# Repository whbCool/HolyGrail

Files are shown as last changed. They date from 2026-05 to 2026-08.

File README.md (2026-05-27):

# TEA@CPP Escape Room 2026: The Holy Grail

update_noTB

The _Holy Grail_ is a custom PCB, designed for the Indiana Jones puzzle as a part of TEA@CPP's "Retro Rewind" 2026 Escape Room. 

This repository includes the KiCad schematic, as well as the code database for the board.

For more details on the code, check out [the introductory walkthrough here](walkthrough.md).

Major Components:
- ESP32-WROOM-32UE
- SC16IS752IPW_128
- CD74HC138QM96Q1
- SN74LVC1G125DBVT
- CDCLVC1106PWR
- 7447715003
- LMR33640
- AP63205WU-7
- 5747842-2
- W5500
- USBLC6-2SC6
- TMJ0026ABNL
- MMBT3904
- CP2102N-A02-GQFN24
- 1812L150_24MR
- LM393DR

Design Requirements:
1. Read data from 12 LD2410C sensors using SPI-to-UART converters.
2. Aggregate sensor data and package it into a JSON payload to be sent to an MQTT broker.
3. USB port for programming and debugging.

More Info: https://drive.google.com/drive/folders/14Y64IZpTN127Q0mva5SdtTZ1QgllTaBJ

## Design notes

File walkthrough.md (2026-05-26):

# Walkthrough: Holy Grail Board Programming Completed

We have successfully designed, implemented, and organized a robust, modular, and thread-safe firmware architecture for the **Holy Grail** custom radar aggregator PCB! The codebase is ready to be compiled, flashed, and tested.

---

## What We Accomplished

### 1. Multiplexed SPI-to-UART Bridge Driver (`sc16is752` Component)
* **Custom Driver ([sc16is752.h](file:///c:/Users/remas/Desktop/PCBs/DarkMagic/Code/HolyGrail/main/sc16is752.h) & [sc16is752.c](file:///c:/Users/remas/Desktop/PCBs/DarkMagic/Code/HolyGrail/main/sc16is752.c)):** Built a complete driver that performs SPI transactions with the six **SC16IS752** chips.
* **Line Decoder Routing:** Built hardware chip-selection functions that dynamically set the binary address on the **CD74HC138** line decoder (`GPIO25`, `26`, `32`) and pull the Active-High Enable pin (`GPIO33`) `HIGH` to assert the target chip's Chip Select (`*CS`).
* **Resolved MISO Bus Contention:** Programmed dynamic control of the **`IC12` MISO buffer OE pin** via **`GPIO27`**. The driver pulls `GPIO27` `LOW` only during an SPI transaction with the SC16IS752 chips and drives it `HIGH` (tri-stating `IC12`) immediately after. This allows the **W5500** to utilize the shared `MISO` line without any electrical conflicts!
* **Exact Integer Baud Division:** Calculated and programmed divisors for the standard high-speed baud rates (e.g. **230400 bps** or **460800 bps**) using the **14.7456 MHz** crystal, guaranteeing a **0.00% baud rate error**.

### 2. W5500 Ethernet Stack & Static IP (`ethernet` Module)
* **Driver Setup ([ethernet.h](file:///c:/Users/remas/Desktop/PCBs/DarkMagic/Code/HolyGrail/main/ethernet.h) & [ethernet.c](file:///c:/Users/remas/Desktop/PCBs/DarkMagic/Code/HolyGrail/main/ethernet.c)):** Configured the ESP-IDF standard Ethernet driver with W5500 SPI MAC and PHY options, mapping hardware Chip Select (`GPIO5`) and Reset (`GPIO15`).
* **ESP-NETIF Event Handling:** Attached the Ethernet driver to the ESP-NETIF TCP/IP stack with custom static IP parameters (`192.168.1.150`, gateway `192.168.1.1`) and custom DNS (`192.168.1.1`).

### 3. MQTT JSON Telemetry Publisher (`mqtt` Module)
* **Client Setup ([mqtt.h](file:///c:/Users/remas/Desktop/PCBs/DarkMagic/Code/HolyGrail/main/mqtt.h) & [mqtt.c](file:///c:/Users/remas/Desktop/PCBs/DarkMagic/Code/HolyGrail/main/mqtt.c)):** Configured the asynchronous ESP-MQTT client to connect to `mqtt://192.168.1.100:1883` once Ethernet acquires an IP.
* **JSON Serialization:** Handles robust string packaging of telemetry data for all 12 radar sensors and publishes it to `holygrail/radar/telemetry` at 10Hz.

### 4. logical-to-Physical Port Mapping & Aggregation (`main`)
* **Logical Mapping ([main.c](file:///c:/Users/remas/Desktop/PCBs/DarkMagic/Code/HolyGrail/main/main.c)):** Built a static mapping table linking logical sensor indexes `Sensor Bank A (1..6)` and `Sensor Bank B (1..6)` to their physical routing connections (U1-U7 chip index and UART channel A/B) on the PCB.
* **FreeRTOS Dual-Core Tasks:**
  1. **`radar_aggregator_task` (Core 0):** High-priority task that sequentially polls all 12 physical UART channels, parses raw frame packets using the `ld2410c` parser, and updates a global state structure.
  2. **`telemetry_publish_task` (Core 1):** Medium-priority task that packages the latest state values into a JSON MQTT payload, publishes it, and toggles the heartbeat `STATUS` LED (`GPIO21`).
  3. **Thread Safety:** Handled race conditions by wrapping table accesses in a FreeRTOS Mutex.

---

## Codebase Architecture

```mermaid
classDiagram
    class MainApp {
        +app_main()
        +init_board_hardware()
        +radar_aggregator_task()
        +telemetry_publish_task()
    }
    class SC16IS752_Driver {
        +sc16is752_init(config)
        +sc16is752_select_chip(idx)
        +sc16is752_deselect_all()
        +sc16is752_read_reg(chip, chan, reg, val)
        +sc16is752_write_reg(chip, chan, reg, val)
        +sc16is752_configure_uart(chip, chan, baud)
        +sc16is752_read_bytes(chip, chan, buf, max)
    }
    class Ethernet_Driver {
        +ethernet_init(config)
        +ethernet_is_connected()
    }
    class MQTT_Publisher {
        +mqtt_init()
        +mqtt_is_connected()
        +mqtt_publish_telemetry(payload)
    }
    class LD2410C_Parser {
        +ld2410c_parse_target_data(frame, len, data)
    }

    MainApp --> SC16IS752_Driver : Polls U1-U7
    MainApp --> Ethernet_Driver : Starts W5500
    MainApp --> MQTT_Publisher : Sends JSON
    MainApp --> LD2410C_Parser : Parses Bytes
```

---

## How to Compile & Verify

Since you have an established ESP-IDF environment in VS Code pointing to `C:\esp\v6.0.1\esp-idf`, compiling is extremely simple:

### Step 1: Compile in VS Code
1. Open the project folder in VS Code.
2. Click the **Build** icon (gear icon) in the bottom status bar, or press `Ctrl+E` followed by `B`.
3. The VS Code ESP-IDF extension will handle the virtual environment and automatically compile the project into the `build/` directory.

### Step 2: Flash the Board
1. Connect the Holy Grail board to your computer using a USB-C cable (CP2102N UART bridge).
2. Ensure the correct COM port is selected in the bottom status bar.
3. Click the **Flash** icon (lightning bolt icon) in the status bar to upload the compiled binary to the ESP32.

### Step 3: Verify Telemetry
1. Open the **ESP-IDF Monitor** in VS Code (monitor icon) to view the real-time logging output.
2. You will see:
   * **W5500 initialization status** and network link updates.
   * **Static IP printouts** once the link gets initialized.
   * **Real-time sensor parsing states** (Moving, Stationary, or None) as target values change.
3. Connect a laptop to the local Ethernet network, run an MQTT Broker (like Mosquitto) on `192.168.1.100`, and use **MQTT Explorer** subscribed to `holygrail/radar/telemetry` to view the aggregated JSON frames arriving at 10Hz!

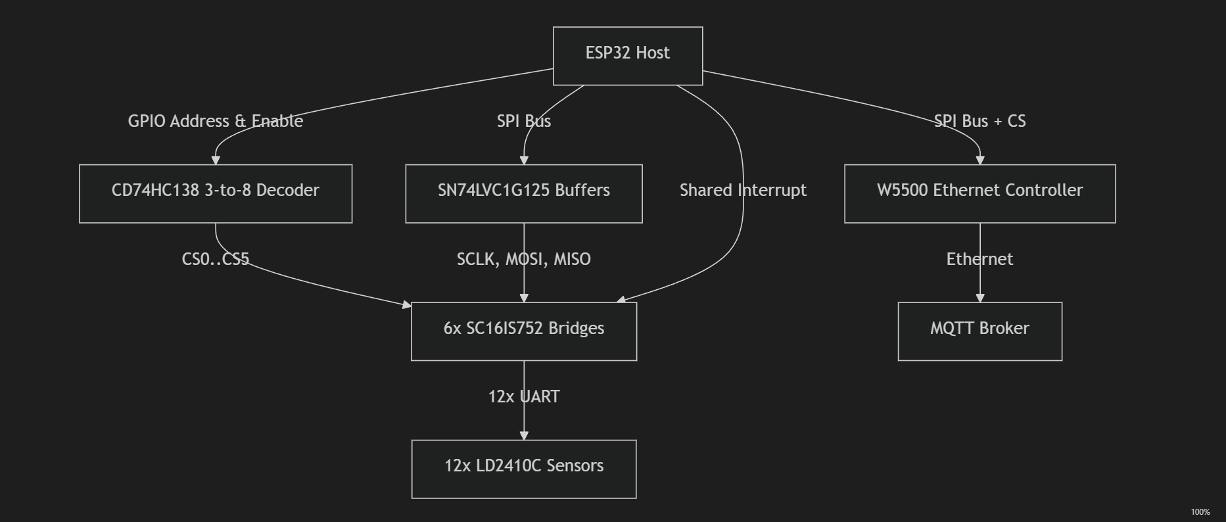
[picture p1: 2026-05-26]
Logic Diagram.png

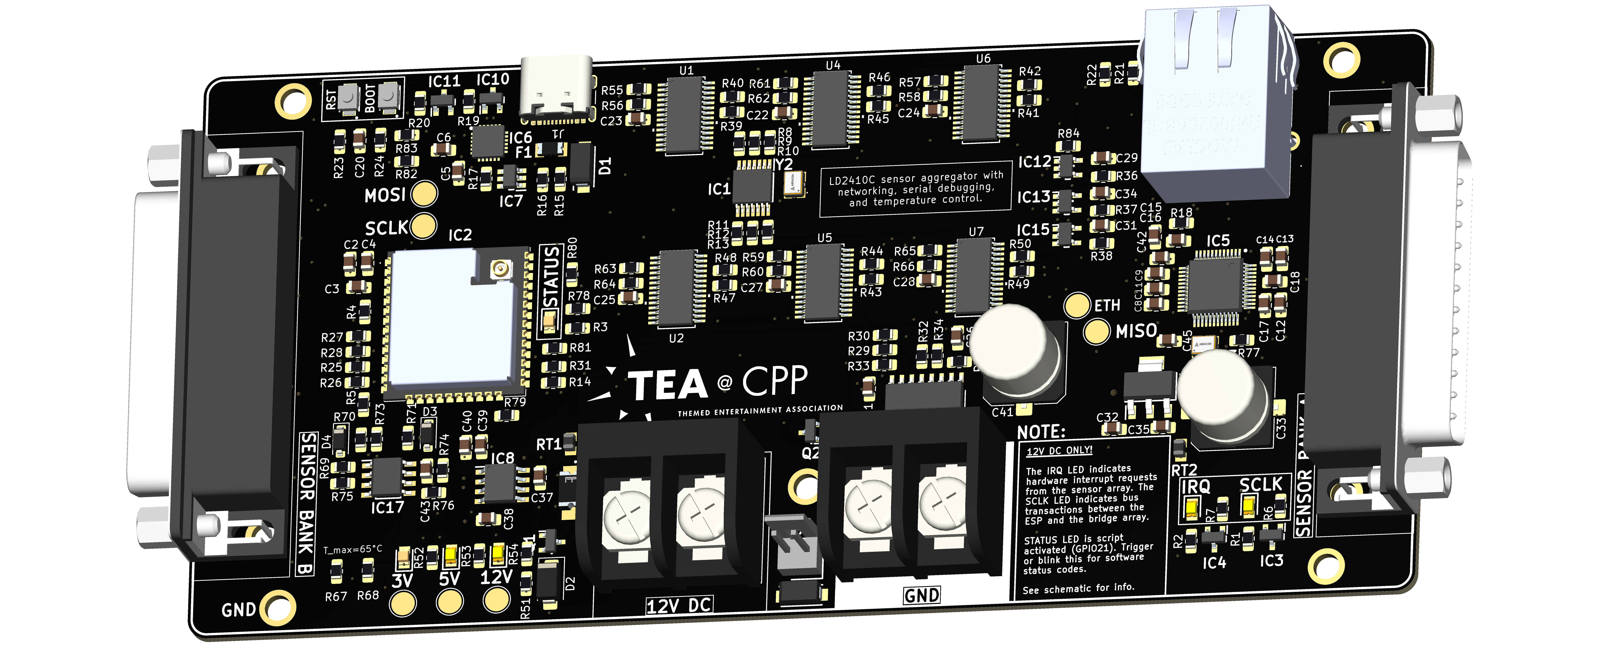
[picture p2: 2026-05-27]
PCB/DarkMagic.png

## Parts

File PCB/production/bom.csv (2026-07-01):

Designator | Footprint | Quantity | Value | LCSC Part #
12V1 | LEDC2012X90N | 1 | HSMC-C170
3V1, STATUS1 | LEDC2012X80N | 2 | HSMG-C170
5V1 | LEDC2012X90N | 1 | HSMA-C170
C1, C10, C12, C13, C14, C15, C16, C17, C18, C19, C2, C20, C21, C22, C23, C24, C25, C26, C27, C28, C29, C30, C31, C34, C35, C37, C42, C43, C44, C45, C46, C47, C50, C6, C8, C9 | 0805 | 36 | 0.1uF
C11 | 0805 | 1 | 10nF
C3, C32, C38, C4 | 0805 | 4 | 10uF
C33 | C_Elec_10x10.2 | 1 | 33uF
C39, C40, C49, C52, C53 | 0805 | 5 | 22uF
C41 | C_Elec_10x10.2 | 1 | 47uF
C48 | 0805 | 1 | 1uF
C5, C7 | 0805 | 2 | 4.7uF
C51 | 0805 | 1 | 220nF
C54 | 0805 | 1 | 39pF
D1, D5 | DIOM5226X230N | 2 | B130-13-F
D2 | D_SMA | 1 | SMBJ26A
D3, D4 | D_SOD-123 | 2 | 1N4148W
F1 | FUSC3216X74N | 1 | NANOSMDC050F_13.2-2
F2 | 1812L010DR | 1 | 1812L150_24MR
IC1 | SOP65P640X120-14N | 1 | 5PB1106PGGI8
IC10, IC11, IC3, IC4 | SOT95P240X120-3N | 4 | MMBT3904-AQ
IC12, IC13, IC15 | SOT95P280X145-5N | 3 | SN74LVC1G125DBVT
IC14 | SOT230P700X180-4N | 1 | LM3940IMP-3.3_NOPB
IC17 | SOIC127P600X175-8N | 1 | LM393DR
IC2 | ESP32WROOM32UEN16 | 1 | ESP32-WROOM-32UE-N16
IC5 | QFP50P900X900X160-48N | 1 | W5500
IC6 | QFN50P400X400X80-25N-D | 1 | CP2102N-A02-GQFN24
IC7 | SOT95P280X145-6N | 1 | USBLC6-2SC6
IC8 | SOIC127P600X170-9N | 1 | LMR33640ADDAR
IRQ1, SCLK1 | LEDC2012X90N | 2 | HSMN-C170
J1 | USB_C_Receptacle_GCT_USB4105-xx-A_16P_TopMnt_Horizontal | 1 | USB_C_Receptacle_USB2.0_16P
J2 | TMJ0026ABNL | 1 | TMJ0026ABNL
J3, J6 | 57478422 | 2 | 5747842-2
J7 | SHDR2W69P0X250_1X2_500X530X1040P | 1 | 171825-2
L1 | L_12x12mm_H4.5mm | 1 | 7447715003
Q1 | SOT95P237X112-3N | 1 | SQ2319ADS-T1_BE3
Q2 | SOT95P237X112-3N | 1 | SQ2348ES-T1_BE3
R1, R2, R21, R22, R3 | 0805 | 5 | 330
R10, R11, R12, R13, R29, R30, R32, R33, R34, R35, R36, R37, R38, R39, R40, R41, R42, R43, R44, R45, R46, R47, R48, R49, R50, R55, R56, R57, R58, R59, R60, R61, R62, R63, R64, R65, R66, R77, R78, R79, R8, R80, R81, R9 | 0805 | 44 | 33
R14, R17, R19, R20, R23, R24, R25, R26, R27, R28, R4, R5, R51, R69, R70, R71, R72, R73, R74, R84, R88, R93 | 0805 | 22 | 10k
R15, R16 | 0805 | 2 | 5.1k
R18 | 0805 | 1 | 12.4k
R31, R54, R6, R7 | 0805 | 4 | 4.7k
R52 | 0805 | 1 | 680
R53 | 0805 | 1 | 1.5k
R67, R68 | 0805 | 2 | 2.55K
R75, R76 | 0805 | 2 | 1M
R82 | 0805 | 1 | 22.1k
R83 | 0805 | 1 | 47.5k
R85 | 0805 | 1 | 24.9k
R86, R87 | 0805 | 2 | 100k
R89, R90, R91, R92 | 0805 | 4 | 49.9
RT1, RT2 | THRMC2012X130N | 2 | B57442V5103J062
S1, S2 | B3U1000PB | 2 | B3U-1000P-B
U1, U2, U4, U5, U6, U7 | TSSOP28_SOT361-1_NXP | 6 | SC16IS752IPW_128
U3 | D16 | 1 | CD74HC138QM96Q1
Y2 | ASE24576MHZLCT | 1 | ASE-14.7456MHZ-LC-T
Y3 | ASE24576MHZLCT | 1 | ASE-25.000MHZ-LC-T

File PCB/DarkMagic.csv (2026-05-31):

Reference | Qty | Value | Manufacturer_Part_Number | Mouser Part Number | DNP | Exclude from BOM | Exclude from Board | Datasheet | Manufacturer_Name | Mouser Price/Stock | #
3V1,STATUS1 | 2 | HSMG-C170 | HSMG-C170 | 630-HSMG-C170 |  |  |  | https://datasheet.datasheetarchive.com/originals/distributors/SFDatasheet-4/sf-00083853.pdf | Avago Technologies | https://www.mouser.co.uk/ProductDetail/Broadcom-Avago/HSMG-C170?qs=YDL0qNrpDT4lm8ArMPkMEA%3D%3D | 1
5V1 | 1 | HSMA-C170 | HSMA-C170 | 630-HSMA-C170 |  |  |  | https://docs.broadcom.com/docs/AV02-0112EN | Avago Technologies | https://www.mouser.co.uk/ProductDetail/Broadcom-Avago/HSMA-C170?qs=YDL0qNrpDT47TEfDRX4SKQ%3D%3D | 2
12V1 | 1 | HSMC-C170 | HSMC-C170 | 630-HSMC-C170 |  |  |  | https://docs.broadcom.com/docs/AV02-0112EN | Avago Technologies | https://www.mouser.co.uk/ProductDetail/Broadcom-Avago/HSMA-C170?qs=YDL0qNrpDT47TEfDRX4SKQ%3D%3D | 3
C1,C2,C6,C8,C9,C10,C12,C13,C14,C15,C16,C17,C18,C19,C20,C21,C22,C23,C24,C25,C26,C27,C28,C29,C30,C31,C34,C35,C37,C42,C43,C44,C45,C46,C47 | 35 | 0.1uF | CL21B104KCC5PNC | 187-CL21B104KCC5PNC |  |  |  |  |  |  | 4
C3,C4,C32,C38 | 4 | 10uF | CL21A106KBYQNNE | 187-CL21A106KBYQNNE |  |  |  |  |  |  | 5
C5,C7 | 2 | 4.7uF | CL21A475KACLRNC | 187-CL21A475KACLRNC |  |  |  |  |  |  | 6
C11 | 1 | 10nF | CL21B103KC6WPNC | 187-CL21B103KC6WPNC |  |  |  |  |  |  | 7
C33 | 1 | 33uF | EEH-ZA1K330P | 667-EEH-ZA1K330P |  |  |  |  |  |  | 8
C39,C40,C49,C52,C53 | 5 | 22uF | CL21X226MQQNNNG | 187-CL21X226MQQNNNG |  |  |  |  |  |  | 9
C41 | 1 | 47uF | EEH-ZA1K470P | 667-EEH-ZA1K470P |  |  |  |  |  |  | 10
C48 | 1 | 1uF | CL21B105KOFNNWE | 187-CL21B105KOFNNWE |  |  |  |  |  |  | 11
C51 | 1 | 220nF | CL21B224KBFNFNE | 187-CL21B224KBFNFNE |  |  |  |  |  |  | 12
C54 | 1 | 39pF | CL21C390JBANNNC | 187-CL21C390JBANNNC |  |  |  |  |  |  | 13
D1,D5 | 2 | B130-13-F | B130-13-F | 621-B130-F |  |  |  | https://componentsearchengine.com/Datasheets/2/B130-13-F.pdf | Diodes Incorporated | https://www.mouser.co.uk/ProductDetail/Diodes-Incorporated/B130-13-F?qs=ktxrFkbdJI2hK4V%252BoGYiAQ%3D%3D | 14
D2 | 1 | SMBJ26A | SMBJ26A | 576-SMBJ26A |  |  |  | https://www.littelfuse.com/assetdocs/tvs-diodes-smbj-series-datasheet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 |  |  | 15
D3,D4 | 2 | 1N4148W | 1N4148W-7-F | 621-1N4148W-7-F |  |  |  | https://www.vishay.com/docs/85748/1n4148w.pdf |  |  | 16
F1 | 1 | NANOSMDC050F_13.2-2 | NANOSMDC050F/13.2-2 | 650-NANOC050F/13.2-2 |  |  |  | http://www.littelfuse.com/~/media/electronics/datasheets/resettable_ptcs/littelfuse_ptc_nanosmd_catalog_datasheet.pdf.pdf | LITTELFUSE | https://www.mouser.co.uk/ProductDetail/Littelfuse/NANOSMDC050F-13.2-2?qs=k5V78Jg%2Feq7nuZ2PUwZ3mw%3D%3D | 17
F2 | 1 | 1812L150_24MR | 1812L150/24MR | 576-1812L150/24MR |  |  |  | http://www.littelfuse.com/~/media/electronics/datasheets/resettable_ptcs/littelfuse_ptc_1812l_datasheet.pdf.pdf | LITTELFUSE | https://www.mouser.co.uk/ProductDetail/Littelfuse/1812L150-24MR?qs=PWhpLWeW8wfTVRohZjjbDw%3D%3D | 18
IC1 | 1 | CDCLVC1106PWR | CDCLVC1106PWR | 595-CDCLVC1106PWR |  |  |  | http://www.ti.com/lit/ds/symlink/cdclvc1108.pdf | Texas Instruments | https://www.mouser.co.uk/ProductDetail/Texas-Instruments/CDCLVC1106PWR?qs=CLImetaeaXVZfWEl0J7gng%3D%3D | 19
IC2 | 1 | ESP32-WROOM-32UE-N16 | ESP32-WROOM-32UE-N16 | 356-ESP32WRM32UE28UH |  |  |  | https://www.espressif.com/sites/default/files/documentation/esp32-wroom-32e_esp32-wroom-32ue_datasheet_en.pdf | Espressif Systems | https://www.mouser.co.uk/ProductDetail/Espressif-Systems/ESP32-WROOM-32UE-N16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 | 20
IC3,IC4,IC10,IC11 | 4 | MMBT3904-AQ | MMBT3904-AQ | 637-MMBT3904-AQ |  |  |  | https://media.digikey.com/pdf/Data%20Sheets/ON%20Semiconductor%20PDFs/2N3904,MMBT3904,PZT3904.pdf | Diotec | https://www.mouser.co.uk/ProductDetail/Diotec-Semiconductor/MMBT3904?qs=OlC7AqGiEDkK1MwiyUU6mg%3D%3D | 21
IC5 | 1 | W5500 | W5500 | 950-W5500 |  |  |  | http://wizwiki.net/wiki/lib/exe/fetch.php?media=products:w5500:w5500_ds_v106e_141230.pdf | WIZnet Inc | https://www.mouser.co.uk/ProductDetail/WIZnet/W5500?qs=2vh%252B45pPFtzthUpYPd4pqA%3D%3D | 22
IC6 | 1 | CP2102N-A02-GQFN24 | CP2102N-A02-GQFN24 | 634-CP2102NA02GQFN24 |  |  |  | https://componentsearchengine.com/Datasheets/1/CP2102N-A02-GQFN24.pdf | Silicon Labs | https://www.mouser.co.uk/ProductDetail/Silicon-Labs/CP2102N-A02-GQFN24?qs=u16ybLDytRYKabtL%2FE7DZA%3D%3D | 23
IC7 | 1 | USBLC6-2SC6 | USBLC6-2SC6 | 511-USBLC6-2SC6 |  |  |  | https://www.st.com/resource/en/datasheet/usblc6-2.pdf | STMicroelectronics | https://www.mouser.co.uk/ProductDetail/STMicroelectronics/USBLC6-2SC6?qs=po45yt2pPpu%2FhNIlwQdTlg%3D%3D | 24
IC8 | 1 | LMR33640ADDAR | LMR33640ADDAR | 595-LMR33640ADDAR |  |  |  | https://www.ti.com/lit/gpn/LMR33640 | Texas Instruments | https://www.mouser.co.uk/ProductDetail/Texas-Instruments/LMR33640ADDAR?qs=Cb2nCFKsA8oM9mwy61hs6A%3D%3D | 25
IC12,IC13,IC15 | 3 | SN74LVC1G125DBVT | SN74LVC1G125DBVR | 595-SN74LVC1G125DBVR |  |  |  | http://www.ti.com/lit/gpn/sn74lvc1g125 | Texas Instruments | https://www.mouser.co.uk/ProductDetail/Texas-Instruments/SN74LVC1G125DBVT?qs=pajgIaoyDUhgzq%252B7Owiehg%3D%3D | 26
IC14 | 1 | LM3940IMP-3.3_NOPB | LM3940IMP-3.3/NOPB | 926-LM3940IMP3.3NOPB |  |  |  | http://www.ti.com/lit/ds/symlink/lm3940.pdf | Texas Instruments | https://www.mouser.co.uk/ProductDetail/Texas-Instruments/LM3940IMP-3.3-NOPB?qs=QbsRYf82W3EIVCEt3IRFTQ%3D%3D | 27
IC17 | 1 | LM393DR | LM393DR | 595-LM393DR |  |  |  | https://www.ti.com/lit/ds/symlink/lm393.pdf?ts=1593083953253 | Texas Instruments | https://www.mouser.co.uk/ProductDetail/Texas-Instruments/LM393DR?qs=8k%2FZSzWMuCP%2FrtMSX0i7pQ%3D%3D | 28
IRQ1,SCLK1 | 2 | HSMN-C170 | HSMN-C170 | 630-HSMN-C170 |  |  |  | https://docs.broadcom.com/docs/AV02-0112EN | Avago Technologies | https://www.mouser.co.uk/ProductDetail/Broadcom-Avago/HSMA-C170?qs=YDL0qNrpDT47TEfDRX4SKQ%3D%3D | 29
J1 | 1 | USB_C_Receptacle_USB2.0_16P | UJ20-C-H-G-SMT-1A-P16-TR | 179-CHGSMT1AP16TR |  |  |  | https://www.usb.org/sites/default/files/documents/usb_type-c.zip |  |  | 30
J2 | 1 | TMJ0026ABNL | TMJ0026ABNL | 960-TMJ0026ABNL |  |  |  | https://www.taoglas.com/datasheets/TMJ0026ABNL.pdf | Taoglas | https://www.mouser.co.uk/ProductDetail/Taoglas/TMJ0026ABNL?qs=By6Nw2ByBD3Rf1CzUTefRQ%3D%3D | 31
J3,J6 | 2 | 5747842-2 | DB25-SA-M2 | 737-DB25-SA-M2 |  |  |  | https://www.te.com/commerce/DocumentDelivery/DDEController?Action=srchrtrv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 | Adam Tech |  | 32
J7 | 1 | 171825-2 | 171825-2 | 571-171825-2 |  |  |  | https://www.te.com/commerce/DocumentDelivery/DDEController?Action=showdoc | TE Connectivity | https://www.mouser.co.uk/ProductDetail/TE-Connectivity-Alcoswitch/171825-2?qs=BQnH65u3HD9lGX0fvAq4oA%3D%3D | 33
L1 | 1 | 7447715003 | 7447715003 | 710-7447715003 |  |  |  | https://www.we-online.com/catalog/datasheet/7447715003.pdf | Wurth Elektronik | https://www.mouser.co.uk/ProductDetail/Wurth-Elektronik/7447715003?qs=XJfXErqHgA7n%2FIvZfnta1w%3D%3D | 34
M1 | 1 | FFB0412VHN-B | FFB0412VHN-B | 108-FFB0412VHN-B |  |  | Excluded from board | https://www.mouser.com/datasheet/3/1208/1/FFB0412VHN_B.pdf | Delta |  | 35
Q1 | 1 | SQ2319ADS-T1_BE3 | SQ2319ADS-T1_BE3 | 78-SQ2319ADS-T1_BE3 |  |  |  | https://www.vishay.com/docs/76397/sq2319ads.pdf | Vishay | https://www.mouser.co.uk/ProductDetail/Vishay-Semiconductors/SI2323DDS-T1-GE3?qs=vgn07B5hXavjZXK0uPQNiA%3D%3D | 36
Q2 | 1 | SQ2348ES-T1_BE3 | SQ2348ES-T1_BE3 | 78-SQ2348ES-T1_BE3 |  |  |  | https://www.vishay.com/docs/63706/sq2348es.pdf | Vishay | https://www.mouser.co.uk/ProductDetail/Vishay-Siliconix/SQ2348ES-T1_BE3?qs=TiOZkKH1s2TNKlymt%252BRxUQ%3D%3D | 37
R1,R2,R3,R21,R22 | 5 | 330 | ERJ-PC6B3300V | 667-ERJ-PC6B3300V |  |  |  |  |  |  | 38
R4,R5,R14,R17,R19,R20,R23,R24,R25,R26,R27,R28,R51,R84,R88 | 15 | 10k | ERA-6AEB103V | 667-ERA-6AEB103V |  |  |  |  |  |  | 39
R6,R7 | 2 | 4.7K | ERA-6ARB4751V | 667-ERA-6ARB4751V |  |  |  |  |  |  | 40
R8,R9,R10,R11,R12,R13,R29,R30,R32,R33,R34,R35,R36,R37,R38,R39,R40,R41,R42,R43,R44,R45,R46,R47,R48,R49,R50,R55,R56,R57,R58,R59,R60,R61,R62,R63,R64,R65,R66,R77,R78,R79,R80,R81 | 44 | 33 | ERA-6AHD330V | 667-ERA-6AHD330V |  |  |  |  |  |  | 41
R15,R16 | 2 | 5.1k | ERA-6ARB512V | 667-ERA-6ARB512V |  |  |  |  |  |  | 42
R18 | 1 | 12.4k | ERJ-UP6F1242V | 667-ERJ-UP6F1242V |  |  |  |  |  |  | 43
R31,R54 | 2 | 4.7k | ERJ-UP6D4701V | 667-ERJ-UP6D4701V |  |  |  |  |  |  | 44
R52 | 1 | 680 | ERJ-S06J681V | 667-ERJ-S06J681V |  |  |  |  |  |  | 45
R53 | 1 | 1.5k | ERA-6AEB152V | 667-ERA-6AEB152V |  |  |  |  |  |  | 46
R67,R68 | 2 | 2.55K | ERA-6AEB2551V | 667-ERA-6AEB2551V |  |  |  |  |  |  | 47
R69,R70,R71,R72,R73,R74 | 6 | 10K | ERA-6APB103V | 667-ERA-6APB103V |  |  |  |  |  |  | 48
R75,R76 | 2 | 1M | ERA-6AEB105V | 667-ERA-6AEB105V |  |  |  |  |  |  | 49
R82 | 1 | 22.1k | ERA-6AEB2212V | 667-ERA-6AEB2212V |  |  |  |  |  |  | 50
R83 | 1 | 47.5k | ERA-6AEB4752V | 667-ERA-6AEB4752V |  |  |  |  |  |  | 51
R85 | 1 | 24.9k | ERJ-PB6B2492V | 667-ERJ-PB6B2492V |  |  |  |  |  |  | 52
R86,R87 | 2 | 100k | ERA-6AEB104V | 667-ERA-6AEB104V |  |  |  |  |  |  | 53
R89,R90,R91,R92 | 4 | 49.9 | ERJ-P06F49R9V | 667-ERJ-P06F49R9V |  |  |  |  |  |  | 54
RT1,RT2 | 2 | B57442V5103J062 | B57442V5103J062 | 871-B57442V5103J62 |  |  |  | https://componentsearchengine.com/Datasheets/1/B57442V5103J062.pdf | TDK | https://www.mouser.com/Search/Refine.aspx?Keyword=871-B57442V5103J62 | 55
S1,S2 | 2 | B3U-1000P | B3U-1000P | 653-B3U-1000P |  |  |  | https://www.omron.com/ecb/products/pdf/en-b3u.pdf | OMRON Electronics | https://www.mouser.co.uk/ProductDetail/Omron-Electronics/B3U-1000P?qs=AO7BQMcsEu4ip80xyf2FwA%3D%3D | 56
U1,U2,U4,U5,U6,U7 | 6 | SC16IS752IPW_128 | SC16IS752IPW,128 | 771-SC16IS752IPW128 |  |  |  | https://www.mouser.com/datasheet/3/118/1/SC16IS752_SC16IS762.pdf |  |  | 57
U3 | 1 | CD74HC138QM96Q1 | CD74HC138QM96Q1 | 595-CD74HC138QM96Q1 |  |  |  | https://www.ti.com/lit/gpn/cd74hc138-q1 |  |  | 58
Y2 | 1 | ASE-14.7456MHZ-LC-T | ASE-14.7456MHZ-LC-T | 815-ASE14.7456MHZLCT |  |  |  | https://abracon.com/Oscillators/ASEseries.pdf | ABRACON | https://www.mouser.co.uk/ProductDetail/ABRACON/ASE-147456MHZ-LC-T?qs=ShQ8XZQtgRuXVUohQN10bA%3D%3D | 59
Y3 | 1 | ASE-25.000MHZ-LC-T | ASE-25.000MHZ-LC-T | 815-ASE-25.000MHZ-LC-T |  |  |  | https://abracon.com/Oscillators/ASEseries.pdf | ABRACON | https://www.mouser.co.uk/ProductDetail/ABRACON/ASE-147456MHZ-LC-T?qs=ShQ8XZQtgRuXVUohQN10bA%3D%3D | 60

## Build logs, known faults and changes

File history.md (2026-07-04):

# Holy Grail Aggregator Board - Troubleshooting & Repair History

This document logs the hardware diagnostics, repairs, and software fixes performed to establish communication between the ESP32, the SC16IS752 UART bridge array, the W5500 Ethernet controller, and the HLK-LD2410C radar sensors.

---

## 1. SPI Bus & MISO Isolation Analysis

### Symptom
* Initial firmware returned `0xFF` (all `1`s) for all registers across all six SC16IS752 chips on the SPI bus.

### Diagnostic Actions
* **Bit-Bang Diagnostics**: Wrote a manual GPIO bit-bang SPI routine in `main.c` to control Chip Select (`~CS`), `SCLK`, and `MOSI` independently of the hardware SPI peripheral.
* **Address Line Loopback**: Configured decoder lines (`A0`, `A1`, `A2`, `E3`) as `INPUT_OUTPUT` during testing and successfully read back the driven voltages to verify there were no physical shorts or loading on the decoder inputs.
* **MISO Floating Net Isolation**: 
  * Discovered that when all SC16IS752 chips are deselected or held in reset, the shared `/SO` (MISO) line floats. 
  * The CMOS input stage of the MISO buffer `IC12` Pin 2 drifts high when floating, driving the ESP32 MISO line (`GPIO19`) to `1` (`0xFF`).
  * **Fix**: Enabled the ESP32's internal pull-down resistor on `GPIO19` so that a floating `/SO` net reads back as `0x00` instead of `0xFF`.

---

## 2. SPI Clock Short-to-GND Resolution (`IC15`)

### Symptom
* Loopback checks on the SPI control pins revealed that the SPI Clock Pin (**`SCLK` / `GPIO18`**) was stuck `LOW` (reading `0` even when driven `HIGH`).
* `MOSI` (`GPIO23`) was confirmed to be healthy and toggling.
* The lack of a clock signal prevented all SPI chips and the W5500 from clocking out register handshakes, resulting in total silence.

### Diagnostic Actions
* Traced the SCLK line `/ESP_SCLK` to the input of buffer **`IC15`** (Pin 2) and ground (Pin 3), which are adjacent pins on a SOT-23-5 package.
* Measured resistance to ground on the board and identified a direct solder bridge.

### Repair
* **Physical Fix**: Solder bridge cleared on **`IC15`** pins 2 and 3. SCLK signal was restored, passing the drive-and-readback verification test.

---

## 3. Sensor Wiring & Baud Rate Correction

### Symptom
* After repairing SCLK, SPI communications with the SC16IS752 chips succeeded (returning the expected test pattern `0x55` on the scratchpad registers), but the HLK-LD2410C sensors returned `0` bytes and began getting warm to the touch.

### Diagnostic Actions
* Added rate-limited hex dump logging of raw incoming bytes from the sensors.
* Verified that `rx_len` remained `0` and analyzed the heating behavior.
* **TX/RX Swap Identified**: Determined that the board's TX (outputting idle HIGH) was shorted to the sensor's TX (driving high/low during transmission), causing output driver contention (heating) and preventing the RX line from receiving data.

### Repair & Configuration
* **Physical Cable Fix**: Swapped the TX and RX connections on the sensor cables to match the board's DB25 breakout mapping:
  * **Board RX** (Pin 7 on `J6`, Pin 1 on `J3` for Sensor 1) connects to **Sensor TX**.
  * **Board TX** (Pin 8 on `J6`, Pin 2 on `J3` for Sensor 1) connects to **Sensor RX**.
* **Baud Rate Mismatch Fixed**: 
  * Once the wiring was corrected, raw bytes started arriving, but they appeared as scrambled garbage (`FC 9E 5F AF...`).
  * The sensor defaults to **256,000 baud**, but a 14.7456 MHz crystal on the SC16IS752 can only generate **230,400 baud** (divisor = 4, 0% error) or **307,200 baud** (divisor = 3, 20% error) with integer division.
  * **Fix**: Wireless connection was established with the sensor via the **HLK-Radar** smartphone app over Bluetooth (password: `HiLink`), and the sensor's internal serial port baud rate was changed to **`230400`** to match the board.
  * Optionally, modified the Bluetooth settings on the sensor (changed default password / disabled BLE) to prevent unauthorized remote access.

---

## 4. Software Optimizations & Boot Sequence

* **IOMUX Reclamation**: Added `gpio_reset_pin()` calls at the start of the diagnostic to decouple SCLK, MOSI, and MISO from the hardware SPI peripheral block, allowing standard bit-bang operations.
* **Boot self-test**: Modified `main.c` so the diagnostic prints bus health, address validation, and a W5500 read test on boot, then automatically continues normal startup tasks without halting.
* **W5500 Reset pin mapping**: Updated the hardware mapping (`#define PIN_W5500_RST 17`) to match the user's re-routing of the W5500 hardware reset pin to a dedicated GPIO (GPIO17). This provides independent reset control of the Ethernet chip, resolves conflict with the SC16IS752 reset net (GPIO2), and enables full hardware Ethernet networking.

---

## 5. W5500 Ethernet Controller SPI Diagnosis

### Symptom
* The W5500 Ethernet controller returned `0x00` on the `VERSIONR` (address `0x0039`) SPI read diagnostic at boot, causing the ESP-IDF Ethernet driver to fail initialization with `verify chip ID failed` / `ESP_ERR_INVALID_VERSION`.
* The W5500's physical Link/Activity LEDs on the RJ45 jack were fully functional and blinking, proving the analog PHY was active and negotiating network links.

### Diagnostic Actions
* **Reset Voltage Droop**: 
  * Initially measured **2.6V** on W5500 Pin 37 (`RSTn`). 
  * Floated `GPIO13` in software to prevent any default pull-down conflict on the board's bodge wiring. 
  * Identified that the W5500 reset pin has a Schmitt-trigger input with a logic threshold of $\approx 0.8 \times \text{VDD} = 2.61\text{V}$, causing the 2.6V level to hold the digital core in a state of continuous partial reset while leaving the analog PHY running.
* **Bypass Jumper (GPIO16)**: 
  * Configured `GPIO16` (`J9` Pin 2) to output a permanent logic `HIGH` (3.3V) and jumped it to `J9` Pin 3 (W5500 Reset), raising the W5500's reset pin voltage to a solid **3.26V**.
* **Slow-Motion SPI Logic Analysis**: 
  * Configured a super slow-motion SPI routine (2 seconds per bit) and verified with a multimeter that **SCLK (Pin 33)**, **MOSI (Pin 35)**, and **CS (Pin 32)** were all cleanly transitioning between 0V and 3.2V on the W5500 pins.
  * Measured the W5500's **MISO output (Pin 34)** during the slow-motion register read and observed that it remained stuck at **0.1V** (pulled down by the ESP32 internal pull-down) during all clock cycles, including the 6th data bit where the version register `0x04` should have driven it to 3.3V.

### Final Resolution & Success
* **Root Cause Identified**: 
  * Inspected the KiCad schematic and PCB layout for W5500 pins 37 through 42.
  * Discovered that **Pins 37 through 42** (which contain several reserved pins and strap inputs) were incorrectly tied to Ground or 3.3V on the PCB design, whereas the datasheet specified they should be left as No Connect (NC) or floated.
  * These illegal connections forced the W5500's internal digital core into a test/debug boot halt state, disabling its digital SPI interface block and returning `0x00`.
* **Physical Repair**: 
  * Physically **lifted pins 37 through 42** of the W5500 chip off their PCB pads to isolate them completely.
* **Result**: 
  * The W5500 immediately booted its digital core, successfully completed the SPI register handshake, and returned **`0x04`** (the expected version ID) on the SPI bus.
  * The netif stack successfully mounted, and the ESP32 established a solid TCP/IP connection to the MQTT broker to stream the 12-sensor telemetry.
  * The diagnostic code has been disabled and production Ethernet configuration has been re-enabled in [main.c](file:///c:/Users/remas/Desktop/PCBs/DarkMagic/Code/HolyGrail/main/main.c).

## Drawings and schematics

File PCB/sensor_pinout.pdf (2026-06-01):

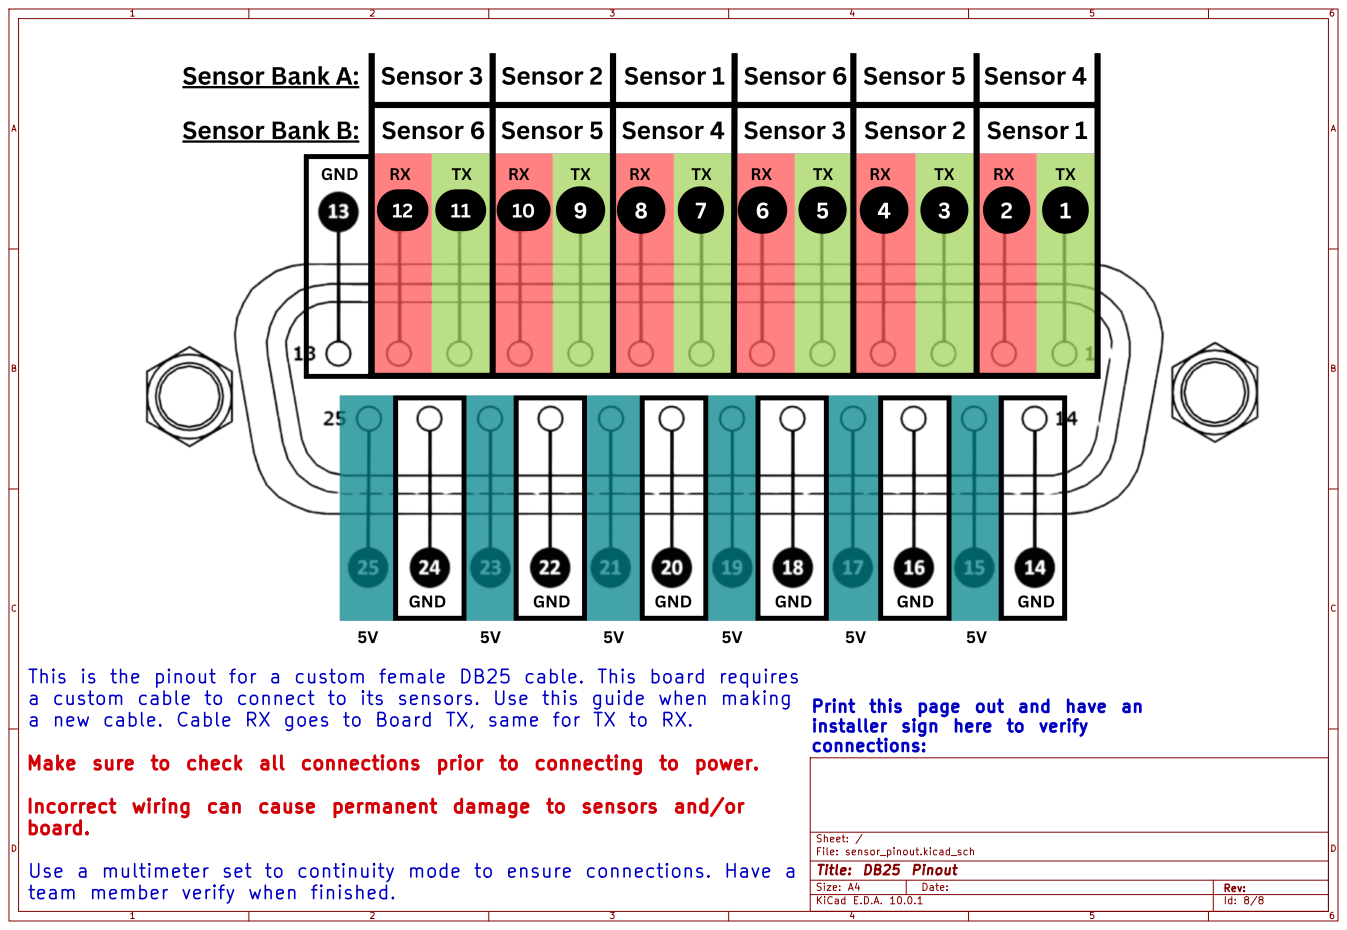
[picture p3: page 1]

This is the pinout for a custom female DB25 cable. This board requires
a custom cable to connect to its sensors. Use this guide when making
a new cable. Cable RX goes to Board TX, same for TX to RX.

Print this page out and have an
installer sign here to verify
connections:

Make sure to check all connections prior to connecting to power.

Incorrect wiring can cause permanent damage to sensors and/or
board.

Use a multimeter set to continuity mode to ensure connections. Have a
team member verify when finished.

Size: A4 | Rev:
KiCad E.D.A. 10.0.1 | Id: 8/8

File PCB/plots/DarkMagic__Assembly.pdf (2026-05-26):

SCLK | | R3 | R39 R15
** | R2 IC14

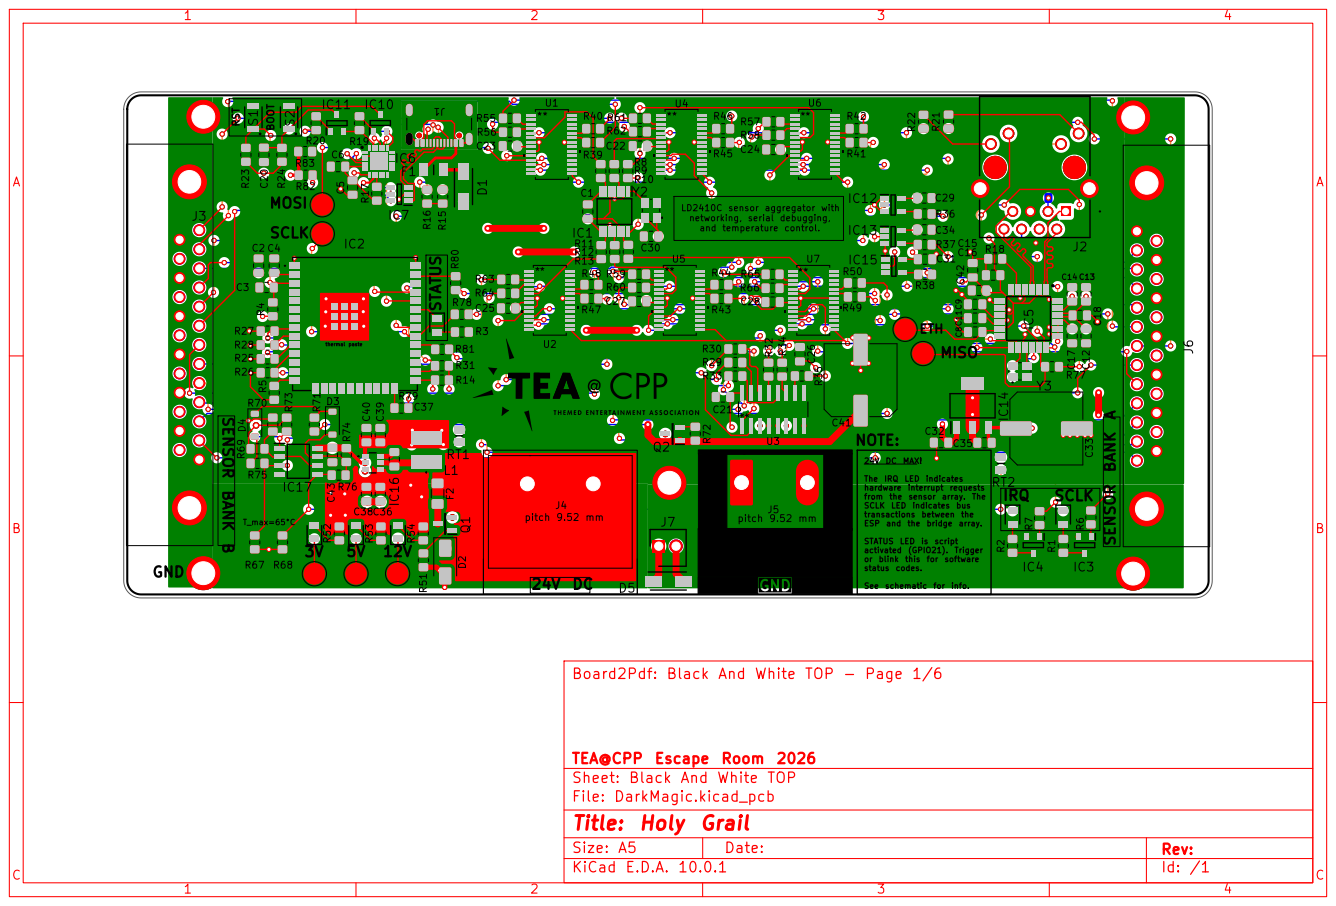
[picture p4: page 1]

LD2410C sensor | | aggregator with

from the sensor array. The SCLK LED indicates bus
transactions between the ESP and the bridge array. STATUS LED is script activated (GPIO21). Trigger or blink this for software

Board2Pdf: Black And White TOP - Page 1/6

TEA@CPP Escape Room 2026
Sheet: Black And White TOP
File: DarkMagic.kicad_pcb
Title: Holy Grail
KiCad E.D.A. 10.0.1

** | R2 IC14
IC10 | F2

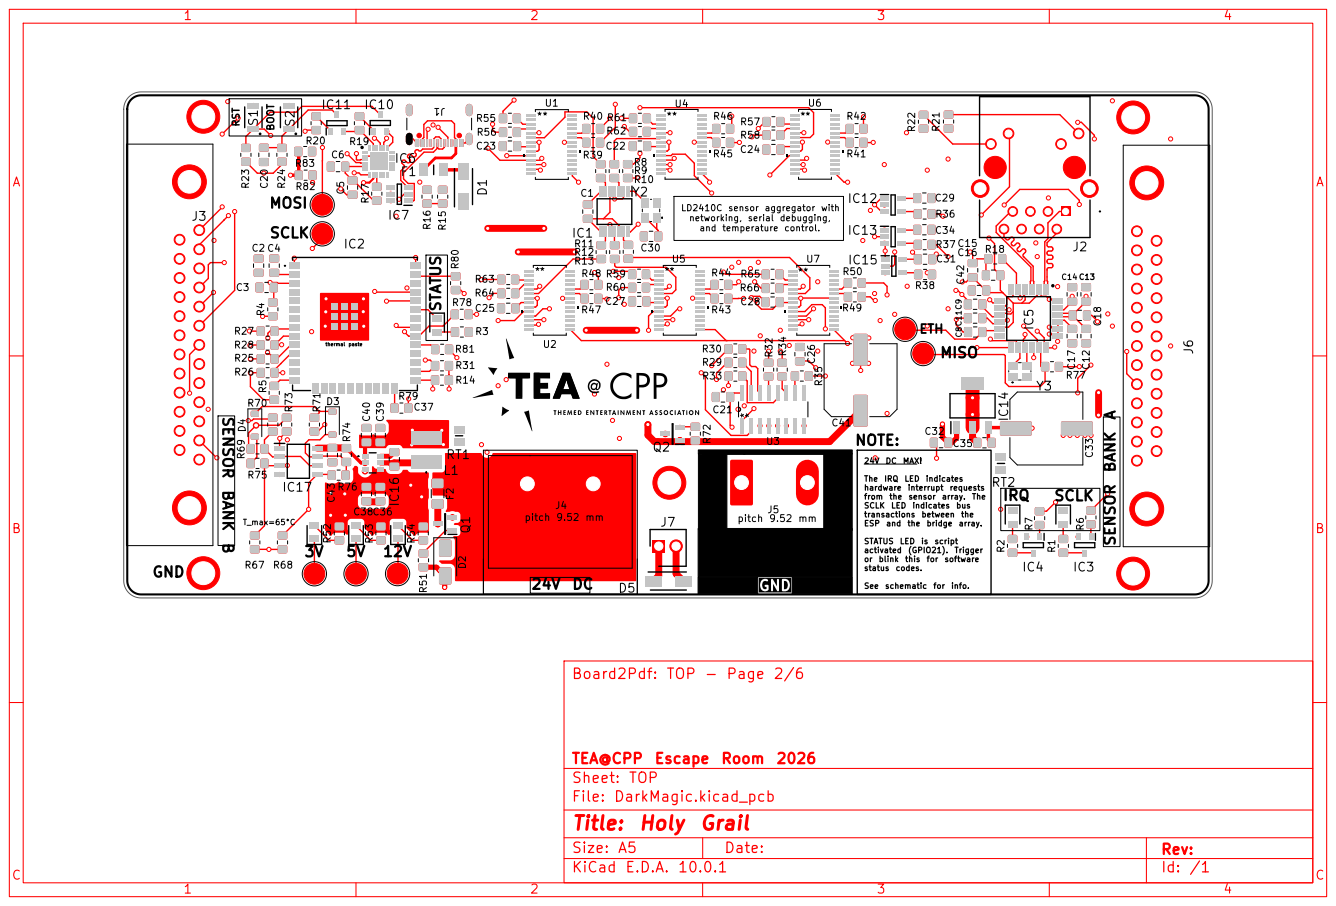
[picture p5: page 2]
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

TEA@CPP Escape Room 2026
Sheet: TOP
File: DarkMagic.kicad_pcb
Title: Holy Grail
KiCad E.D.A. 10.0.1

** | R2 IC14
IC10 | F2

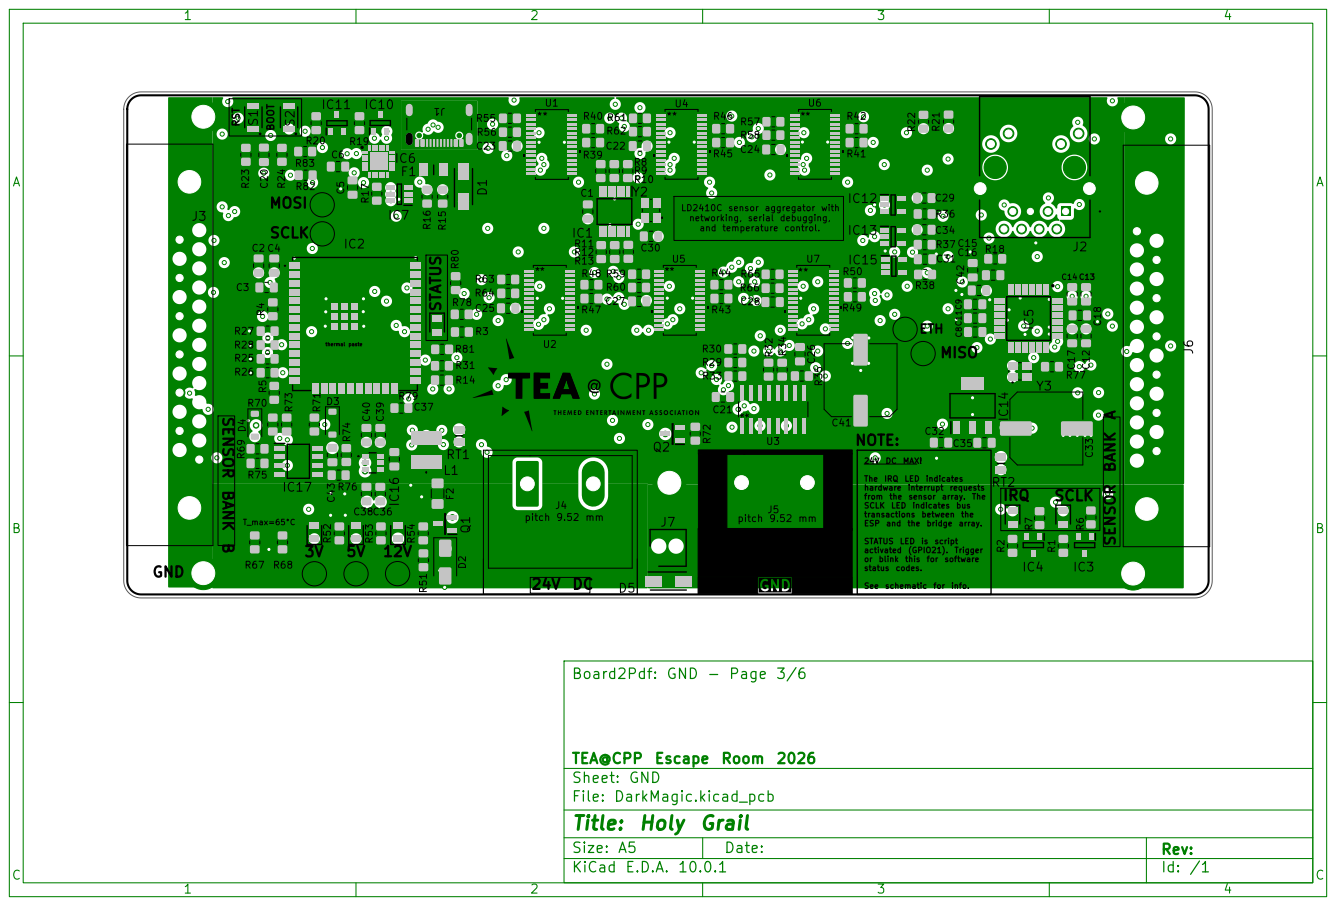
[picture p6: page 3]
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

TEA@CPP Escape Room 2026
Sheet: GND
File: DarkMagic.kicad_pcb
Title: Holy Grail
KiCad E.D.A. 10.0.1

** | R2 IC14
IC10 | F2

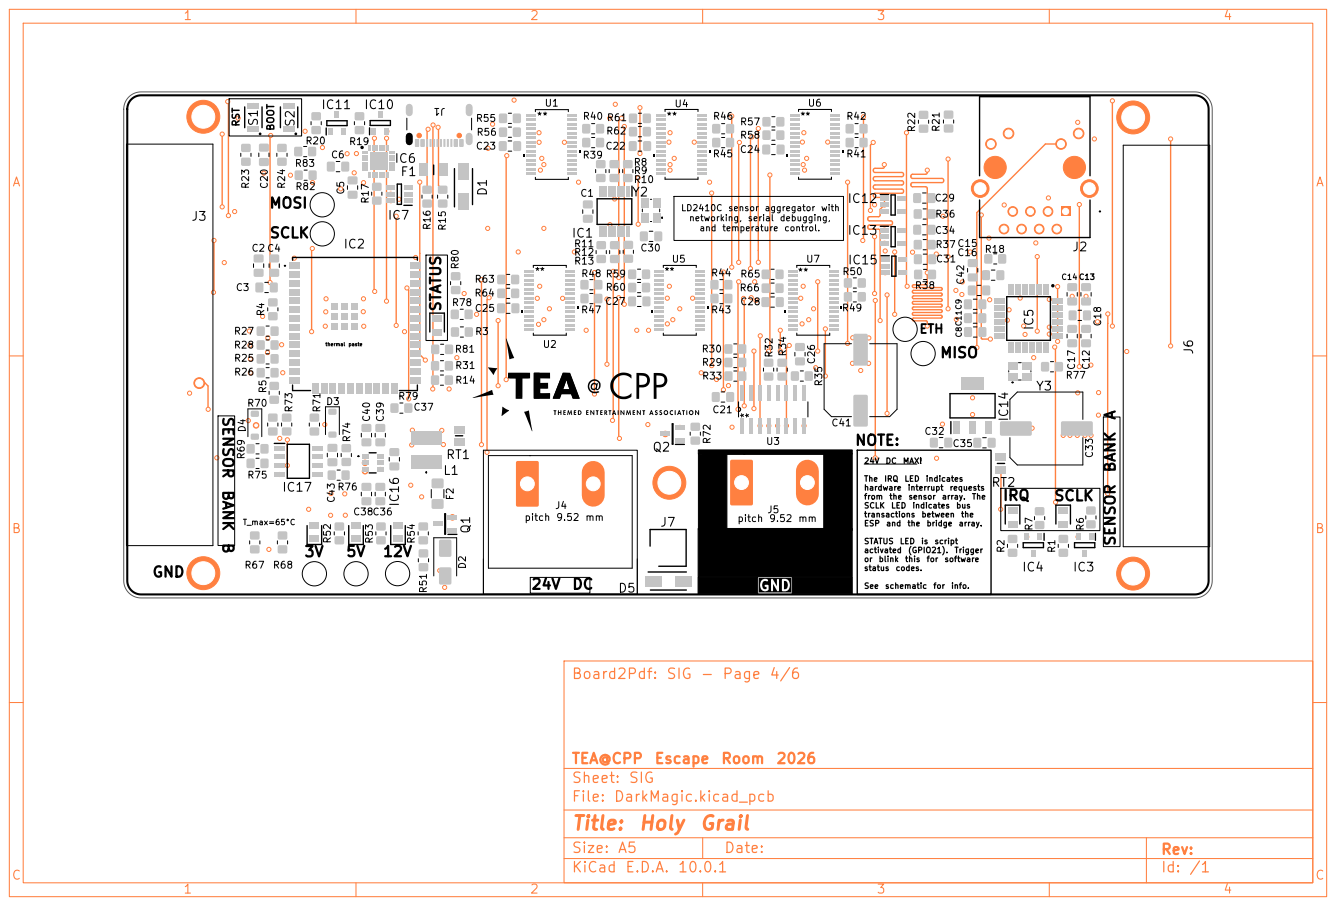
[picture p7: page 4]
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

TEA@CPP Escape Room 2026
Sheet: SIG
File: DarkMagic.kicad_pcb
Title: Holy Grail
KiCad E.D.A. 10.0.1

** | R2 IC14
IC10 | F2

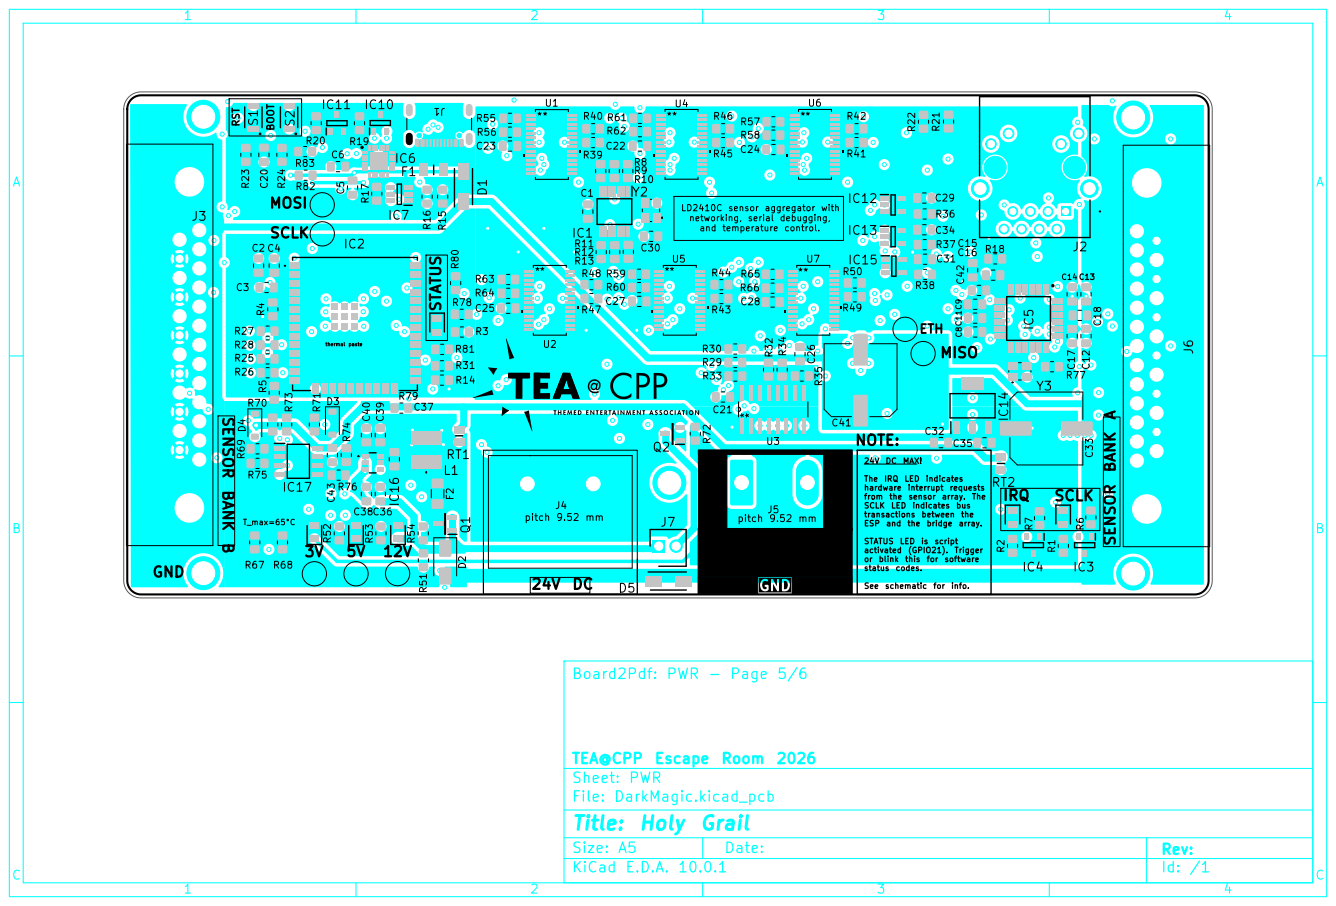
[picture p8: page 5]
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

TEA@CPP Escape Room 2026
Sheet: PWR
File: DarkMagic.kicad_pcb
Title: Holy Grail
KiCad E.D.A. 10.0.1

** | R2 IC14
IC10 | F2

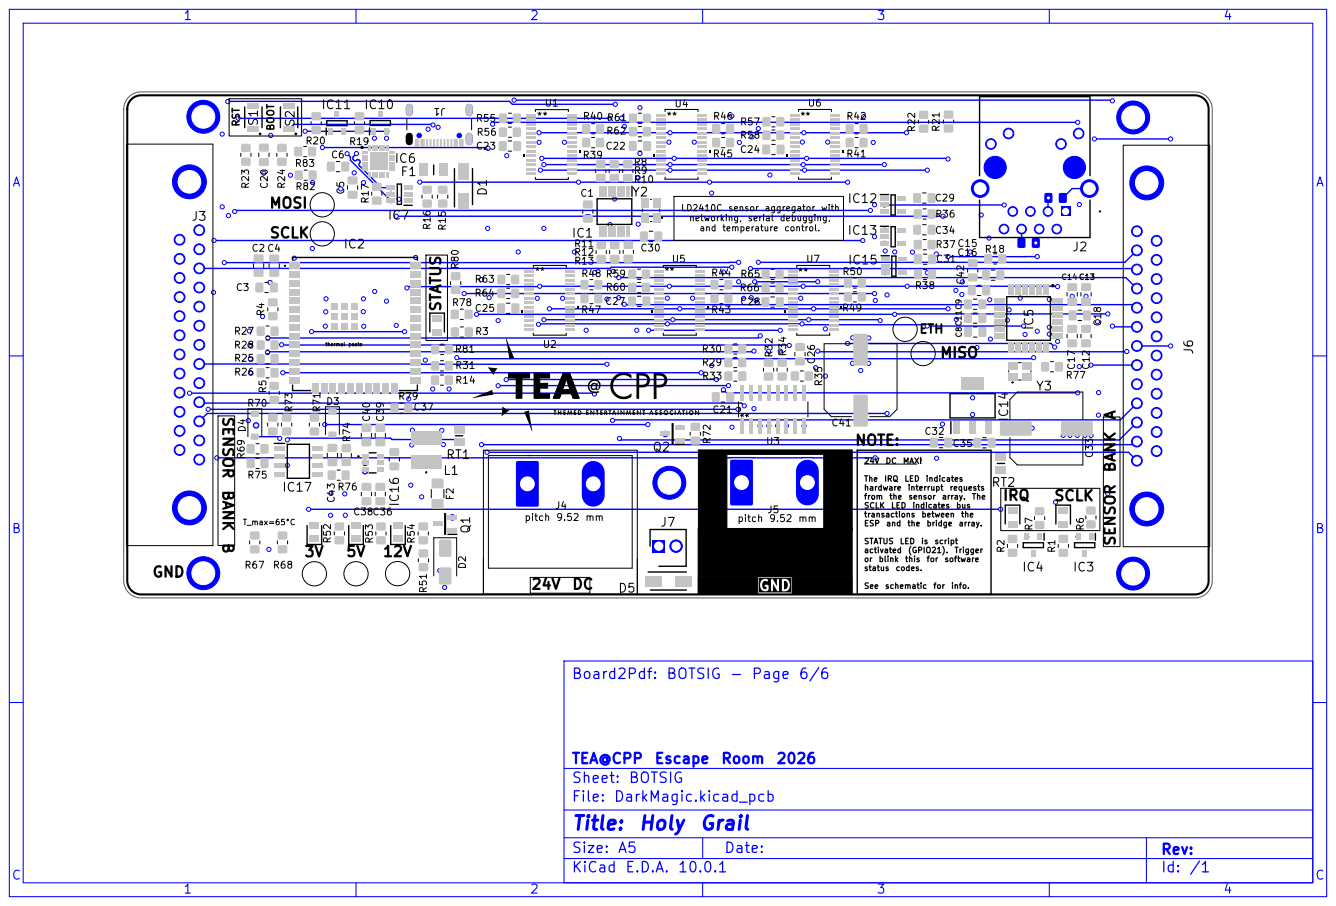
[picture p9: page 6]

MISO

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

TEA@CPP Escape Room 2026
Sheet: BOTSIG
File: DarkMagic.kicad_pcb
Title: Holy Grail
KiCad E.D.A. 10.0.1

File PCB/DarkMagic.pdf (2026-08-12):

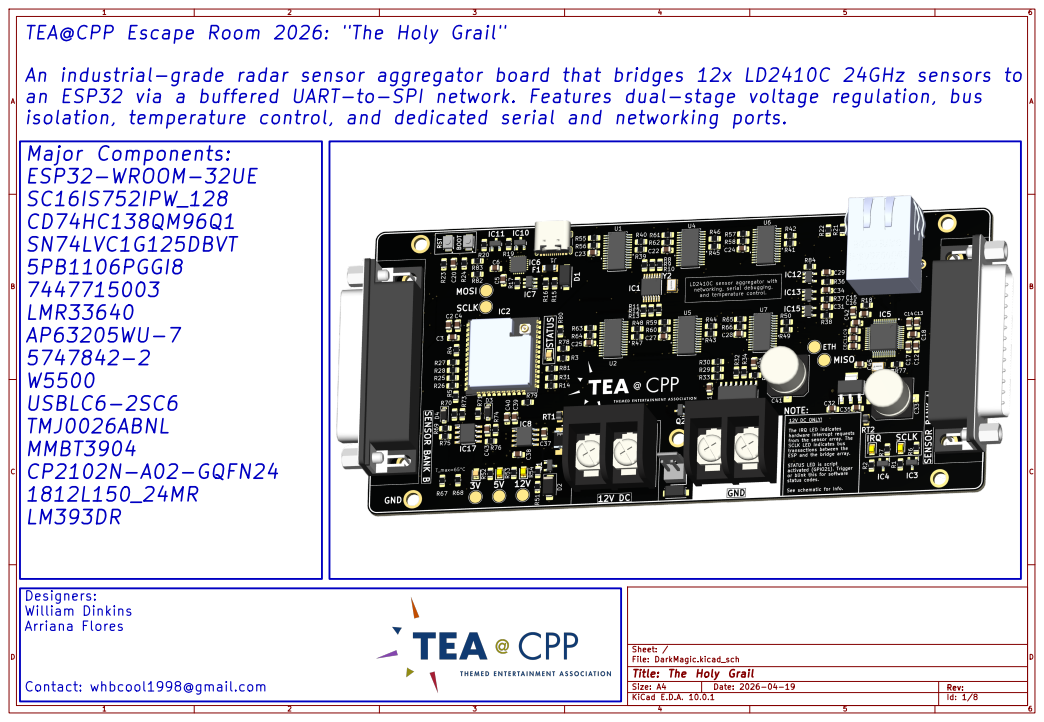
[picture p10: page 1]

TEA@CPP Escape Room 2026: "The Holy Grail"

An industrial-grade radar sensor aggregator board that bridges 12x LD2410C 24GHz sensors to

Sheet: /
File: DarkMagic.kicad_sch
Title: The Holy Grail

Size: A4 | Rev:
KiCad E.D.A. 10.0.1 | Id: 1/8

AB

C

D

AB

C

D Date: 2026-04-27

Size: A4 | Rev:

## Title: Block Diagram

File: block_diagram.kicad_sch

Sheet: /

TEA@CPP Escape Room 2026

William Dinkins

# The architecture begins with the host ESP32 driving a CD74HC138 3-to-8 line decoder to control bus multiplexing. By manipulating three digital address lines, the ESP32 targets the active-low Chip Select (CS) inputs of individual bridge chips. In this design, we utilize six of the

decoder's eight available outputs.

# Each output targets one of six SC16IS752

dual-channel UART-to-SPI bridge controllers.

# Because each bridge chip independently manages two hardware UART channels, this multiplexed network allows the single ESP32 SPI master to interface with twelve discrete LD2410C radar

sensors.

# Telemetry gathered from the sensors is aggregated by the ESP32, formatted into network packets, and transmitted over the local Ethernet

show network.

# NOTE: The original target of this board was to read 24 sensors on one board. To achieve 24 sensors, this board should be duplicated and ran in parallel. Adding 2 more SC16IS752 chips to this design increases the max theoretical capacity to 16 sensors, but requires a complete

board redesign.

W5500

# ESP32

# CD74HC138QM96Q1

# SC16IS752IPW_128

# SC16IS752IPW_128

# LD2410C

# LD2410C

# LD2410C

# LD2410C

# LD2410C

# LD2410C

# LD2410C

# LD2410C

# SC16IS752IPW_128

# LD2410C

# LD2410C

# LD2410C

# SC16IS752IPW_128

# SC16IS752IPW_128

# SC16IS752IPW_128

# LD2410C

# Out To PLC

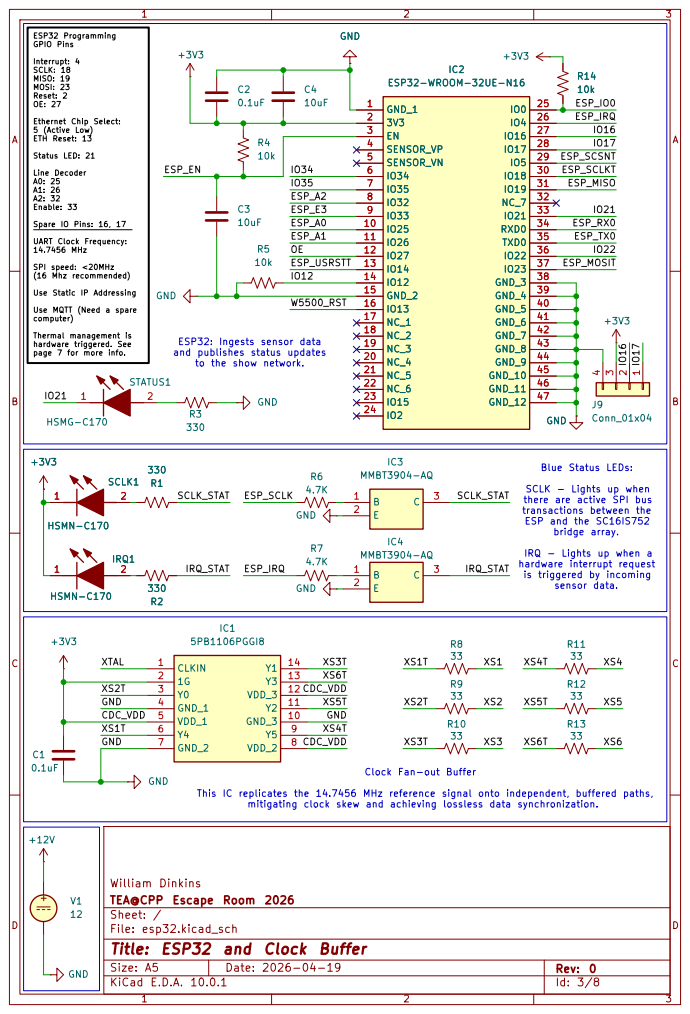
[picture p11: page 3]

GND

Interrupt: 4
SCLK: 18 MISO: 19 MOSI: 23 Reset: 2 OE: 27
10k SCLK1 HSMN-C170

Ethernet Chip Select: 5 (Active Low) ETH Reset: 13

Spare IO Pins: 16, 17 UART Clock Frequency: 14.7456 MHz SPI speed: <20MHz

(16 Mhz recommended) Use Static IP Addressing Use MQTT (Need a spare

and publishes status updates

there are active SPI bus
transactions between the ESP and the SC16IS752

IRQ - Lights up when a
hardware interrupt request
is triggered by incoming

sensor data. Clock Fan-out Buffer This IC replicates the 14.7456 MHz reference signal onto independent, buffered paths,

mitigating clock skew and achieving lossless data synchronization.

TEA@CPP Escape Room 2026
Sheet: /
12 GND

File: esp32.kicad_sch
Title: ESP32 and Clock Buffer

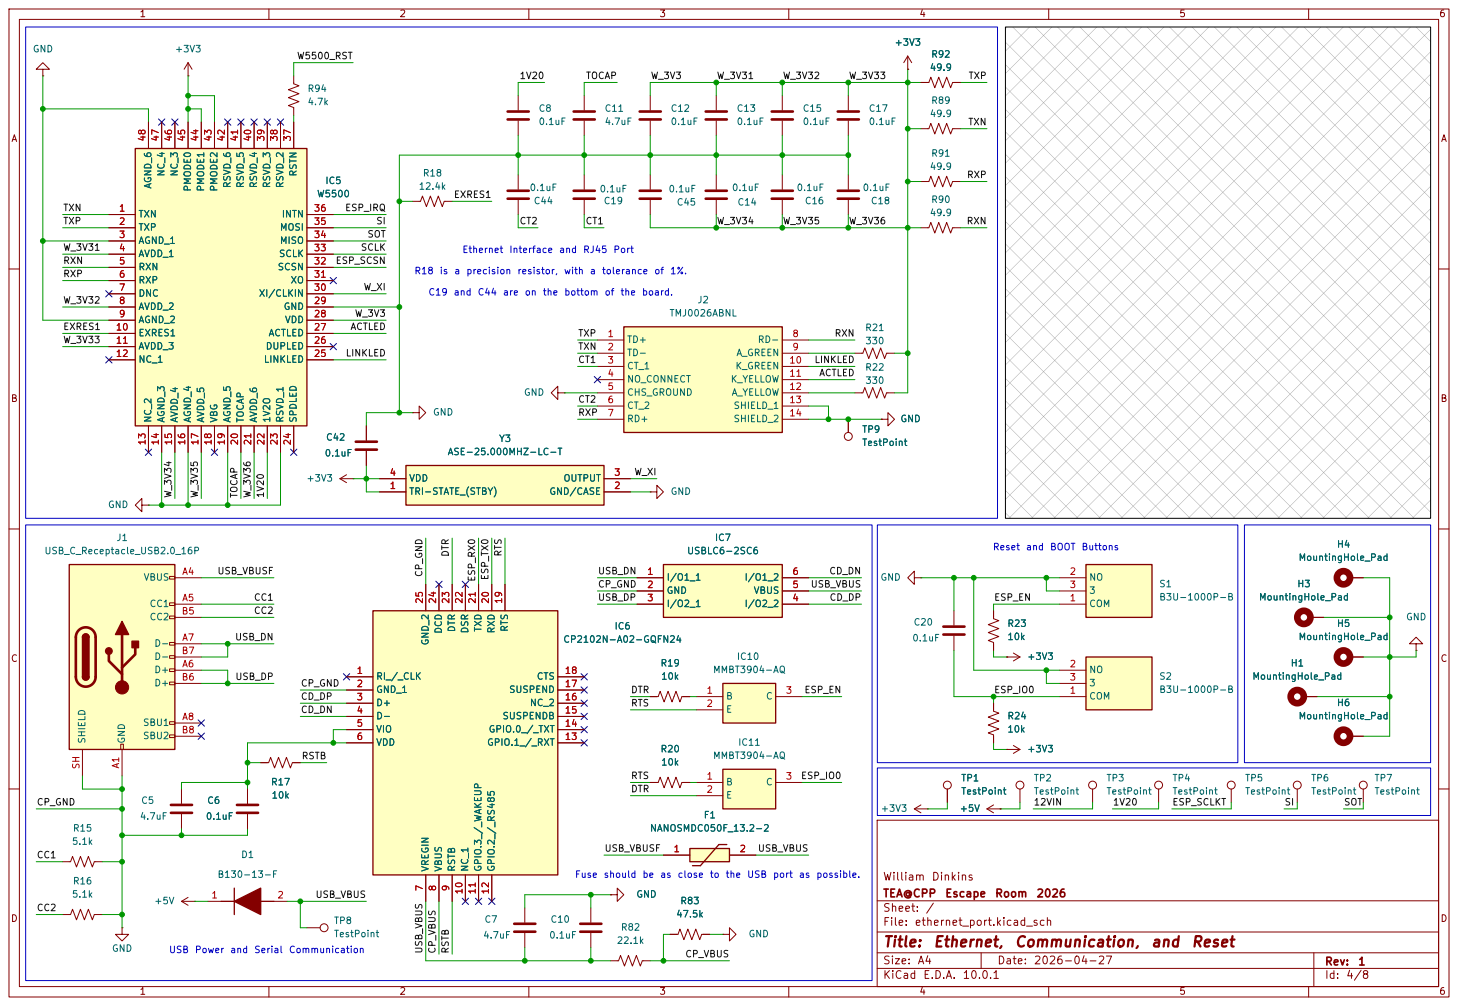
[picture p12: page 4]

Fuse should be as close to the USB port as possible.

TEA@CPP Escape Room 2026
Sheet: /
File: ethernet_port.kicad_sch
Title: Ethernet, Communication, and Reset

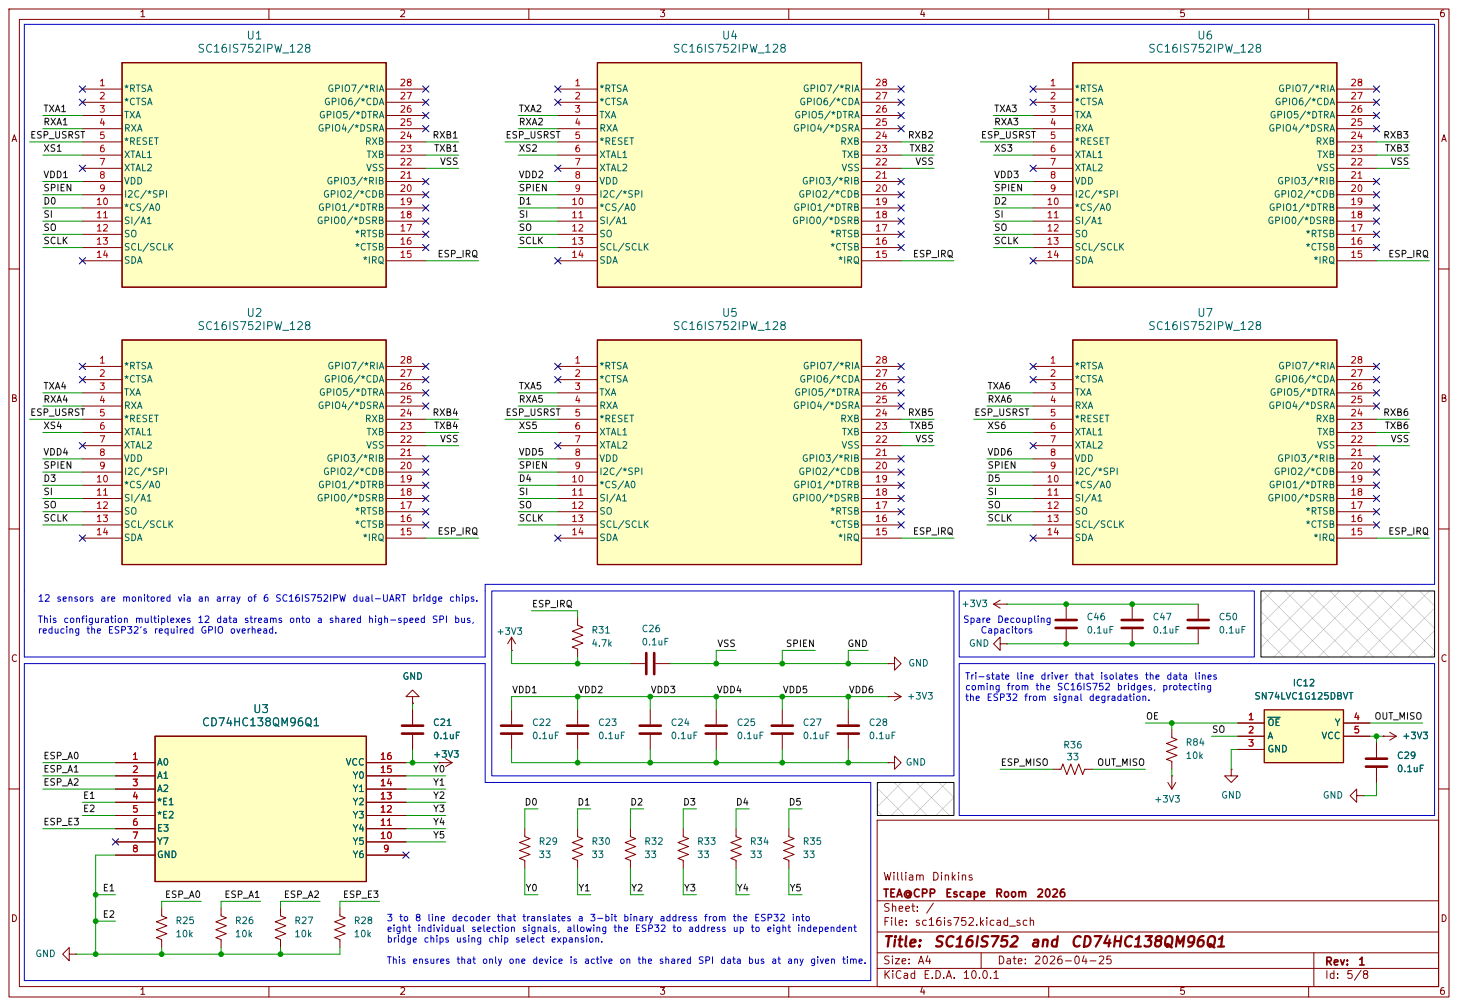
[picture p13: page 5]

12 sensors are monitored via an array of 6 SC16IS752IPW dual-UART bridge chips. This configuration multiplexes 12 data streams onto a shared high-speed SPI bus,

the ESP32 from signal degradation. 3 to 8 line decoder that translates a 3-bit binary address from the ESP32 into

TEA@CPP Escape Room 2026
Sheet: /
File: sc16is752.kicad_sch
Title: SC16IS752 and CD74HC138QM96Q1

eight individual selection signals, allowing the ESP32 to address up to eight independent

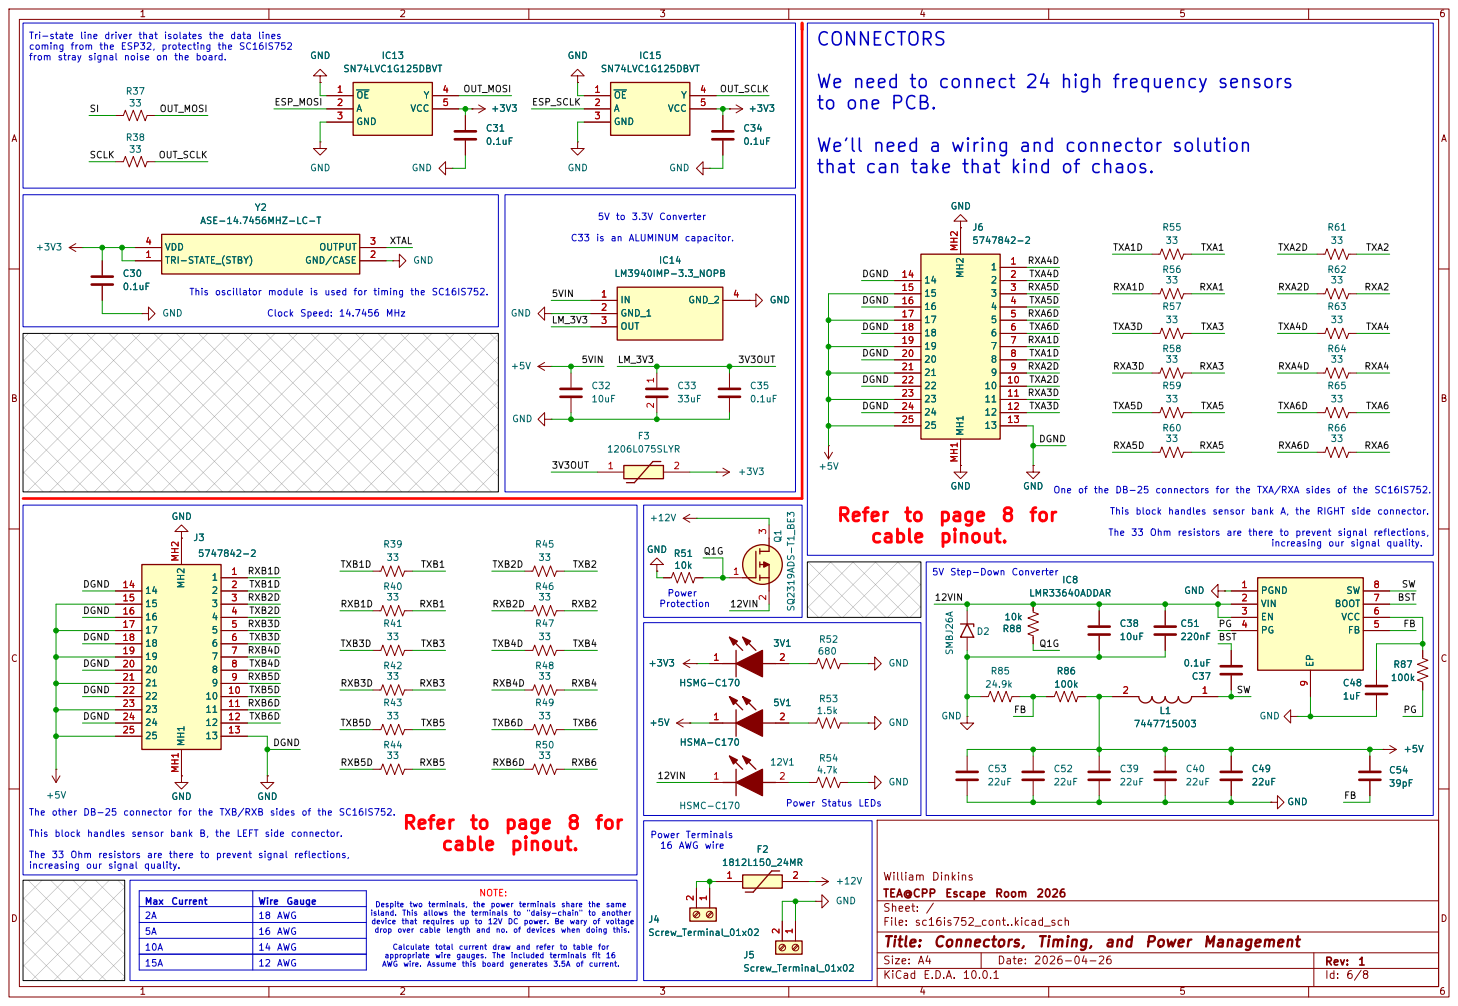
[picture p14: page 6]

Tri-state line driver that isolates the data lines coming from the ESP32, protecting the SC16IS752

We need to connect 24 high frequency sensors
to one PCB.

We'll need a wiring and connector solution

increasing our signal quality. Power Status LEDs

The other DB-25 connector for the TXB/RXB sides of the SC16IS752. This block handles sensor bank B, the LEFT side connector. The 33 Ohm resistors are there to prevent signal reflections,

TEA@CPP Escape Room 2026
Sheet: /
File: sc16is752_cont..kicad_sch
Title: Connectors, Timing, and Power Management

Despite two terminals, the power terminals share the same
island. This allows the terminals to "daisy-chain" to another device that requires up to 12V DC power. Be wary of voltage drop over cable length and no. of devices when doing this. Calculate total current draw and refer to table for appropriate wire gauges. The included terminals fit 16

AWG wire. Assume this board generates 3.5A of current.


GND

Incorporates a ~0.5 second soft-start. C41 is an ALUMINUM capacitor! GND

Fan Controller Set to turn on a fan when temperatures reach ~65° C. Thermistors measure the temperature of the LMR33640 and the AP63205. LM393DR follows OR Logic.
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

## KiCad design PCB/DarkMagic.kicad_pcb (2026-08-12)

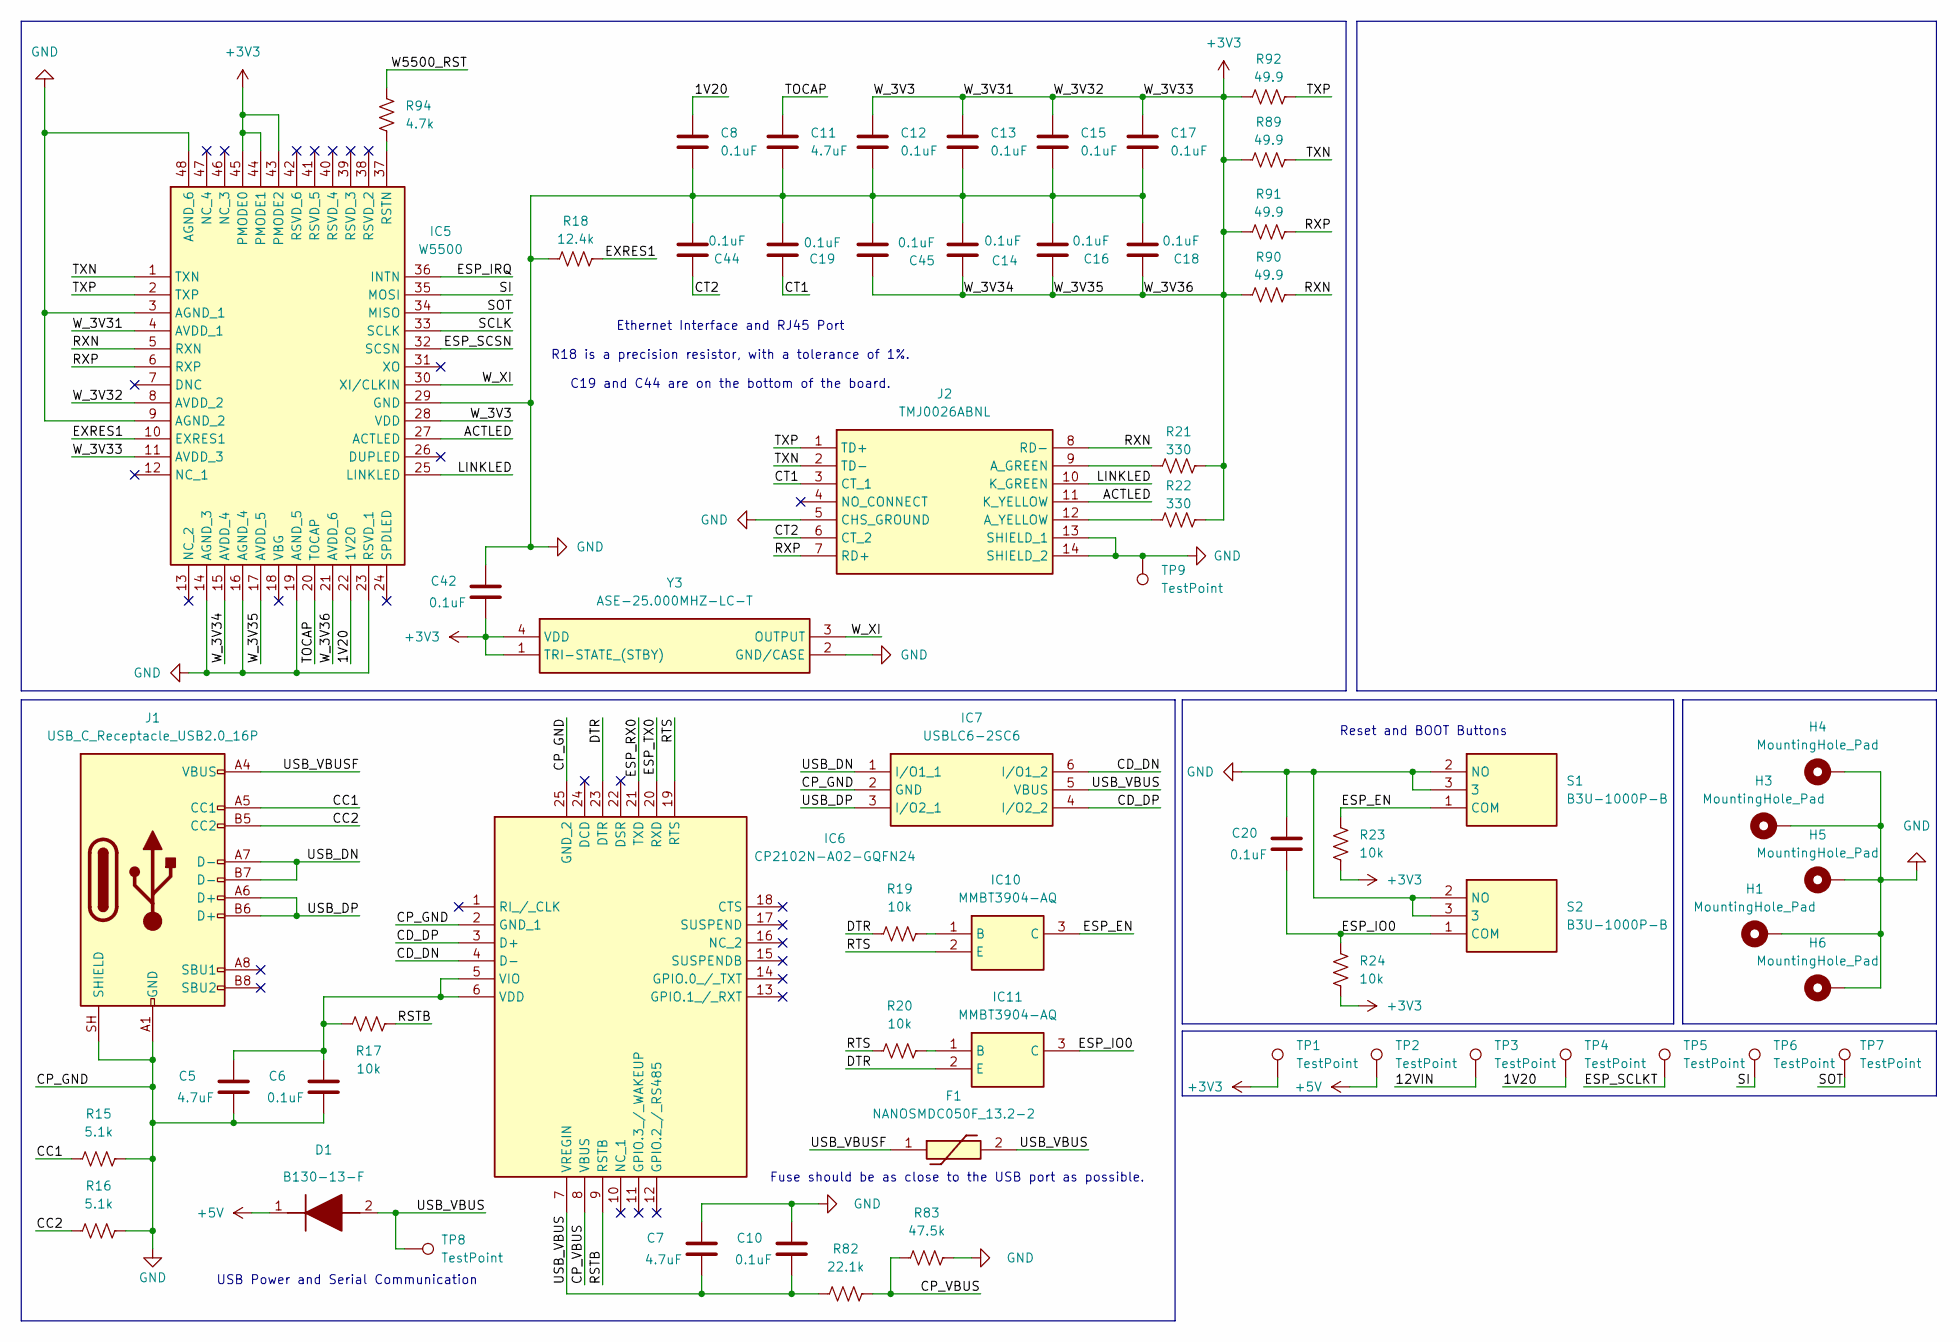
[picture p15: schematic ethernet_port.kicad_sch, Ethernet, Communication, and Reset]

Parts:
C5, C7: 4.7uF; C_0805_2012Metric_Pad1.18x1.45mm_HandSolder; Manufacturer_Part_Number CL21A475KACLRNC; Mouser Part Number 187-CL21A475KACLRNC
C6, C8, C10, C12, C13, C14, C15, C16, C17, C18, C19, C20, C42, C44, C45: 0.1uF; C_0805_2012Metric_Pad1.18x1.45mm_HandSolder; Manufacturer_Part_Number CL21B104KCC5PNC; Mouser Part Number 187-CL21B104KCC5PNC
C11: 4.7uF; C_0805_2012Metric_Pad1.18x1.45mm_HandSolder; Manufacturer_Part_Number CL21B103KC6WPNC; Mouser Part Number 187-CL21B103KC6WPNC
D1: B130-13-F; DIOM5226X230N; Mouser Part Number 621-B130-F
F1: NANOSMDC050F_13.2-2; FUSC3216X74N; Mouser Part Number 650-NANOC050F/13.2-2
H1, H3, H4, H5, H6: MountingHole_Pad; MountingHole_3.2mm_M3_MOD
IC5: W5500; QFP50P900X900X160-48N; Mouser Part Number 950-W5500
IC6: CP2102N-A02-GQFN24; QFN50P400X400X80-25N-D; Mouser Part Number 634-CP2102NA02GQFN24
IC7: USBLC6-2SC6; SOT95P280X145-6N; Mouser Part Number 511-USBLC6-2SC6
IC10, IC11: MMBT3904-AQ; SOT95P240X120-3N; Mouser Part Number 637-MMBT3904-AQ
J1: USB_C_Receptacle_USB2.0_16P; USB_C_Receptacle_GCT_USB4105-xx-A_16P_TopMnt_Horizontal; Manufacturer_Part_Number UJ20-C-H-G-SMT-1A-P16-TR; Mouser Part Number 179-CHGSMT1AP16TR
J2: TMJ0026ABNL; Mouser Part Number 960-TMJ0026ABNL
R15, R16: 5.1k; R_0805_2012Metric_Pad1.20x1.40mm_HandSolder; Manufacturer_Part_Number ERA-6ARB512V; Mouser Part Number 667-ERA-6ARB512V
R17, R19, R20, R23, R24: 10k; R_0805_2012Metric_Pad1.20x1.40mm_HandSolder; Manufacturer_Part_Number ERA-6AEB103V; Mouser Part Number 667-ERA-6AEB103V
R18: 12.4k; R_0805_2012Metric_Pad1.20x1.40mm_HandSolder; Manufacturer_Part_Number ERJ-UP6F1242V; Mouser Part Number 667-ERJ-UP6F1242V
R21, R22: 330; R_0805_2012Metric_Pad1.20x1.40mm_HandSolder; Manufacturer_Part_Number ERJ-PC6B3300V; Mouser Part Number 667-ERJ-PC6B3300V
R82: 22.1k; R_0805_2012Metric_Pad1.20x1.40mm_HandSolder; Manufacturer_Part_Number ERA-6AEB2212V; Mouser Part Number 667-ERA-6AEB2212V
R83: 47.5k; R_0805_2012Metric_Pad1.20x1.40mm_HandSolder; Manufacturer_Part_Number ERA-6AEB4752V; Mouser Part Number 667-ERA-6AEB4752V
R89, R90, R91, R92: 49.9; R_0805_2012Metric_Pad1.20x1.40mm_HandSolder; Manufacturer_Part_Number ERJ-P06F49R9V; Mouser Part Number 667-ERJ-P06F49R9V
R94: 4.7k; R_0805_2012Metric_Pad1.20x1.40mm_HandSolder; Manufacturer_Part_Number ERA-6AEB103V; Mouser Part Number 667-ERA-6AEB103V
S1, S2: B3U-1000P-B; B3U1000PB; Mouser Part Number 653-B3U-1000P-B
TP1, TP2, TP3, TP4, TP5, TP6, TP7, TP8, TP9: TestPoint; TestPoint_Pad_D3.0mm
Y3: ASE-25.000MHZ-LC-T; ASE25000MHZLCT; Mouser Part Number 815-ASE-25.000MHZ-LC-T

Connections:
+5V: D1.1 (K), TP2.1 (1_1); also elsewhere on the board
/1V20: C8.1, IC5.22 (1V2O), TP4.1 (1_1)
/12VIN: TP3.1 (1_1); also elsewhere on the board
/ACTLED: IC5.27 (ACTLED), J2.11 (K_YELLOW)
/CC1: J1.A5 (CC1), R15.1
/CC2: J1.B5 (CC2), R16.1
/CD_DN: IC6.4 (D-), IC7.6 (I/O1_2)
/CD_DP: IC6.3 (D+), IC7.4 (I/O2_2)
/CP_VBUS: IC6.8 (VBUS), R82.1, R83.1
/CT1: C19.2, J2.3 (CT_1)
/CT2: C44.1, J2.6 (CT_2)
/DTR: IC6.23 (DTR), IC11.2 (E), R19.1
/ESP_EN: IC10.3 (C), R23.2, S1.1 (COM); also elsewhere on the board
/ESP_IO0: C20.1, IC11.3 (C), R24.2, S2.1 (COM); also elsewhere on the board
/ESP_IRQ: IC5.36 (INTN); also elsewhere on the board
/ESP_RX0: IC6.21 (TXD); also elsewhere on the board
/ESP_SCLKT: TP5.1 (1_1); also elsewhere on the board
/ESP_SCSN: IC5.32 (SCSN); also elsewhere on the board
/ESP_TX0: IC6.20 (RXD); also elsewhere on the board
/EXRES1: IC5.10 (EXRES1), R18.2
/LINKLED: IC5.25 (LINKLED), J2.10 (K_GREEN)
/RSTB: IC6.9 (RSTB), R17.2
/RTS: IC6.19 (RTS), IC10.2 (E), R20.1
/RXN: IC5.5 (RXN), J2.8 (RD-), R90.2
/RXP: IC5.6 (RXP), J2.7 (RD+), R91.2
/SCLK: IC5.33 (SCLK); also elsewhere on the board
/SI: IC5.35 (MOSI), TP6.1 (1_1); also elsewhere on the board
/SOT: IC5.34 (MISO), TP7.1 (1_1); also elsewhere on the board
/TOCAP: C11.1, IC5.20 (TOCAP)
/TXN: IC5.1 (TXN), J2.2 (TD-), R89.2
/TXP: IC5.2 (TXP), J2.1 (TD+), R92.2
/USB_DN: IC7.1 (I/O1_1), J1.A7 (D-), J1.B7 (D-)
/USB_DP: IC7.3 (I/O2_1), J1.A6 (D+), J1.B6 (D+)
/USB_VBUS: C7.1, C10.1, D1.2 (A), F1.2, IC6.7 (VREGIN), IC7.5 (VBUS), R82.2, TP8.1 (1_1)
/USB_VBUSF: F1.1, J1.A4 (VBUS), J1.A9 (VBUS), J1.B4 (VBUS), J1.B9 (VBUS)
/W5500_RST: R94.1; also elsewhere on the board
/W_XI: IC5.30 (XI/CLKIN), Y3.3 (OUTPUT)
unnamed: IC5.37 (RSTN), R94.2
unnamed: C5.2, C6.2, IC6.5 (VIO), IC6.6 (VDD), R17.1
unnamed: IC10.1 (B), R19.2
unnamed: IC11.1 (B), R20.2
unnamed: J2.9 (A_GREEN), R21.1
unnamed: J2.12 (A_YELLOW), R22.1

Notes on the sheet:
Ethernet Interface and RJ45 Port R18 is a precision resistor, with a tolerance of 1%. C19 and C44 are on the bottom of the board.
USB Power and Serial Communication
Reset and BOOT Buttons
Fuse should be as close to the USB port as possible.

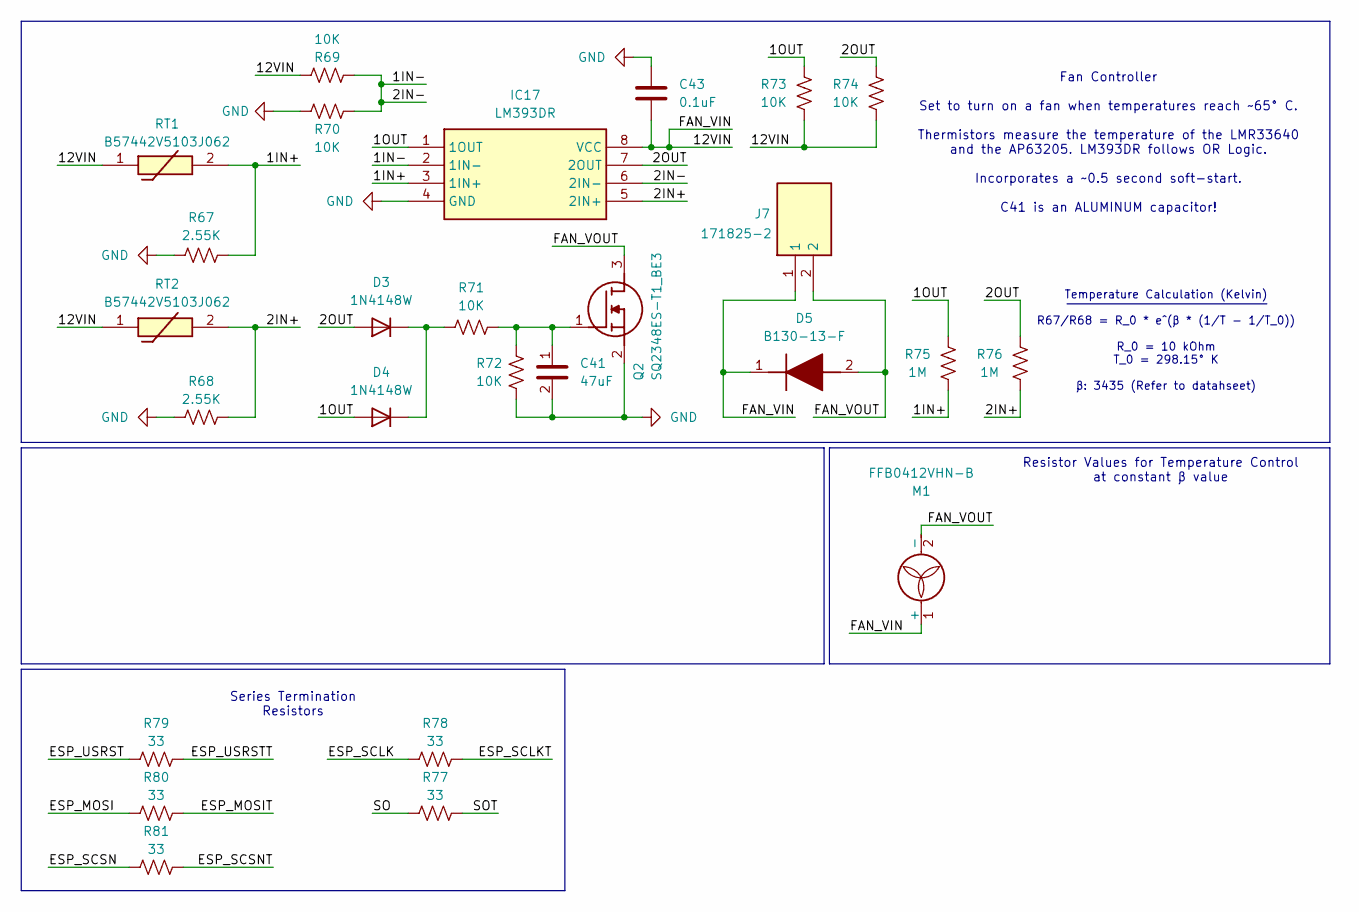
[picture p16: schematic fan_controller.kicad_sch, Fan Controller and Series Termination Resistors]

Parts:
C41: 47uF; C_Elec_10x10.2; Manufacturer_Part_Number EEH-ZA1K470P; Mouser Part Number 667-EEH-ZA1K470P
C43: 0.1uF; C_0805_2012Metric_Pad1.18x1.45mm_HandSolder; Manufacturer_Part_Number CL21B104KCC5PNC; Mouser Part Number 187-CL21B104KCC5PNC
D3, D4: 1N4148W; D_SOD-123; Manufacturer_Part_Number 1N4148W-7-F; Mouser Part Number 621-1N4148W-7-F
D5: B130-13-F; DIOM5226X230N; Mouser Part Number 621-B130-F
IC17: LM393DR; SOIC127P600X175-8N; Mouser Part Number 595-LM393DR
J7: 171825-2; SHDR2W69P0X250_1X2_500X530X1040P; Mouser Part Number 571-171825-2
M1: FFB0412VHN-B; Manufacturer_Part_Number FFB0412VHN-B; Mouser Part Number 108-FFB0412VHN-B
Q2: SQ2348ES-T1_BE3; SOT95P237X112-3N; Mouser Part Number 78-SQ2348ES-T1_BE3
R67, R68: 2.55K; R_0805_2012Metric_Pad1.20x1.40mm_HandSolder; Manufacturer_Part_Number ERA-6AEB2551V; Mouser Part Number 667-ERA-6AEB2551V
R69, R70, R71, R72, R73, R74: 10K; R_0805_2012Metric_Pad1.20x1.40mm_HandSolder; Manufacturer_Part_Number ERA-6APB103V; Mouser Part Number 667-ERA-6APB103V
R75, R76: 1M; R_0805_2012Metric_Pad1.20x1.40mm_HandSolder; Manufacturer_Part_Number ERA-6AEB105V; Mouser Part Number 667-ERA-6AEB105V
R77, R78, R79, R80, R81: 33; R_0805_2012Metric_Pad1.20x1.40mm_HandSolder; Manufacturer_Part_Number ERA-6AHD330V; Mouser Part Number 667-ERA-6AHD330V
RT1, RT2: B57442V5103J062; THRMC2012X130N; Mouser Part Number 871-B57442V5103J62

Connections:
/1IN+: IC17.3 (1IN+), R67.1, R75.1, RT1.2
/1IN-: IC17.2 (1IN-), IC17.6 (2IN-), R69.2, R70.1
/1OUT: D4.2 (A), IC17.1 (1OUT), R73.2, R75.2
/2IN+: IC17.5 (2IN+), R68.1, R76.1, RT2.2
/2OUT: D3.2 (A), IC17.7 (2OUT), R74.2, R76.2
/12VIN: C43.2, D5.1 (K), IC17.8 (VCC), J7.1, M1.1 (+), R69.1, R73.1, R74.1, RT1.1, RT2.1; also elsewhere on the board
/ESP_MOSI: R80.2; also elsewhere on the board
/ESP_MOSIT: R80.1; also elsewhere on the board
/ESP_SCLK: R78.2; also elsewhere on the board
/ESP_SCLKT: R78.1; also elsewhere on the board
/ESP_SCSN: R81.2; also elsewhere on the board
/ESP_SCSNT: R81.1; also elsewhere on the board
/ESP_USRST: R79.2; also elsewhere on the board
/ESP_USRSTT: R79.1; also elsewhere on the board
/FAN_VOUT: D5.2 (A), J7.2, M1.2 (-), Q2.3 (D)
/SO: R77.2; also elsewhere on the board
/SOT: R77.1; also elsewhere on the board
unnamed: D3.1 (K), D4.1 (K), R71.1
unnamed: C41.1, Q2.1 (G), R71.2, R72.2

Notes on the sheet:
Resistor Values for Temperature Control at constant β value
Series Termination Resistors
Fan Controller Set to turn on a fan when temperatures reach ~65° C. Thermistors measure the temperature of the LMR33640 and the AP63205. LM393DR follows OR Logic. Incorporates a ~0.5 second soft-start. C41 is an ALUMINUM capacitor!
Temperature Calculation (Kelvin) R67/R68 = R_0 * e^(β * (1/T - 1/T_0)) R_0 = 10 kOhm T_0 = 298.15° K β: 3435 (Refer to datahseet)

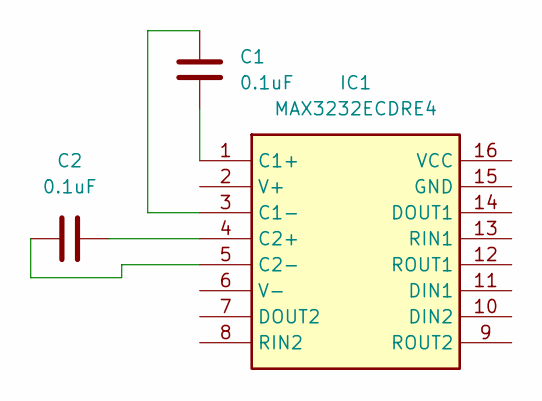
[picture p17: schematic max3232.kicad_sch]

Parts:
C1, C2: 0.1uF
IC1: MAX3232ECDRE4; SOIC127P600X175-16N; Manufacturer_Part_Number MAX3232ECDRE4; Mouser Part Number 595-MAX3232ECDRE4

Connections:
/XS1T: IC1.6 (Y4); also elsewhere on the board
/XS3T: IC1.14 (Y1); also elsewhere on the board
/XS4T: IC1.9 (Y5); also elsewhere on the board
/XS5T: IC1.11 (Y2); also elsewhere on the board
/XS6T: IC1.13 (Y3); also elsewhere on the board

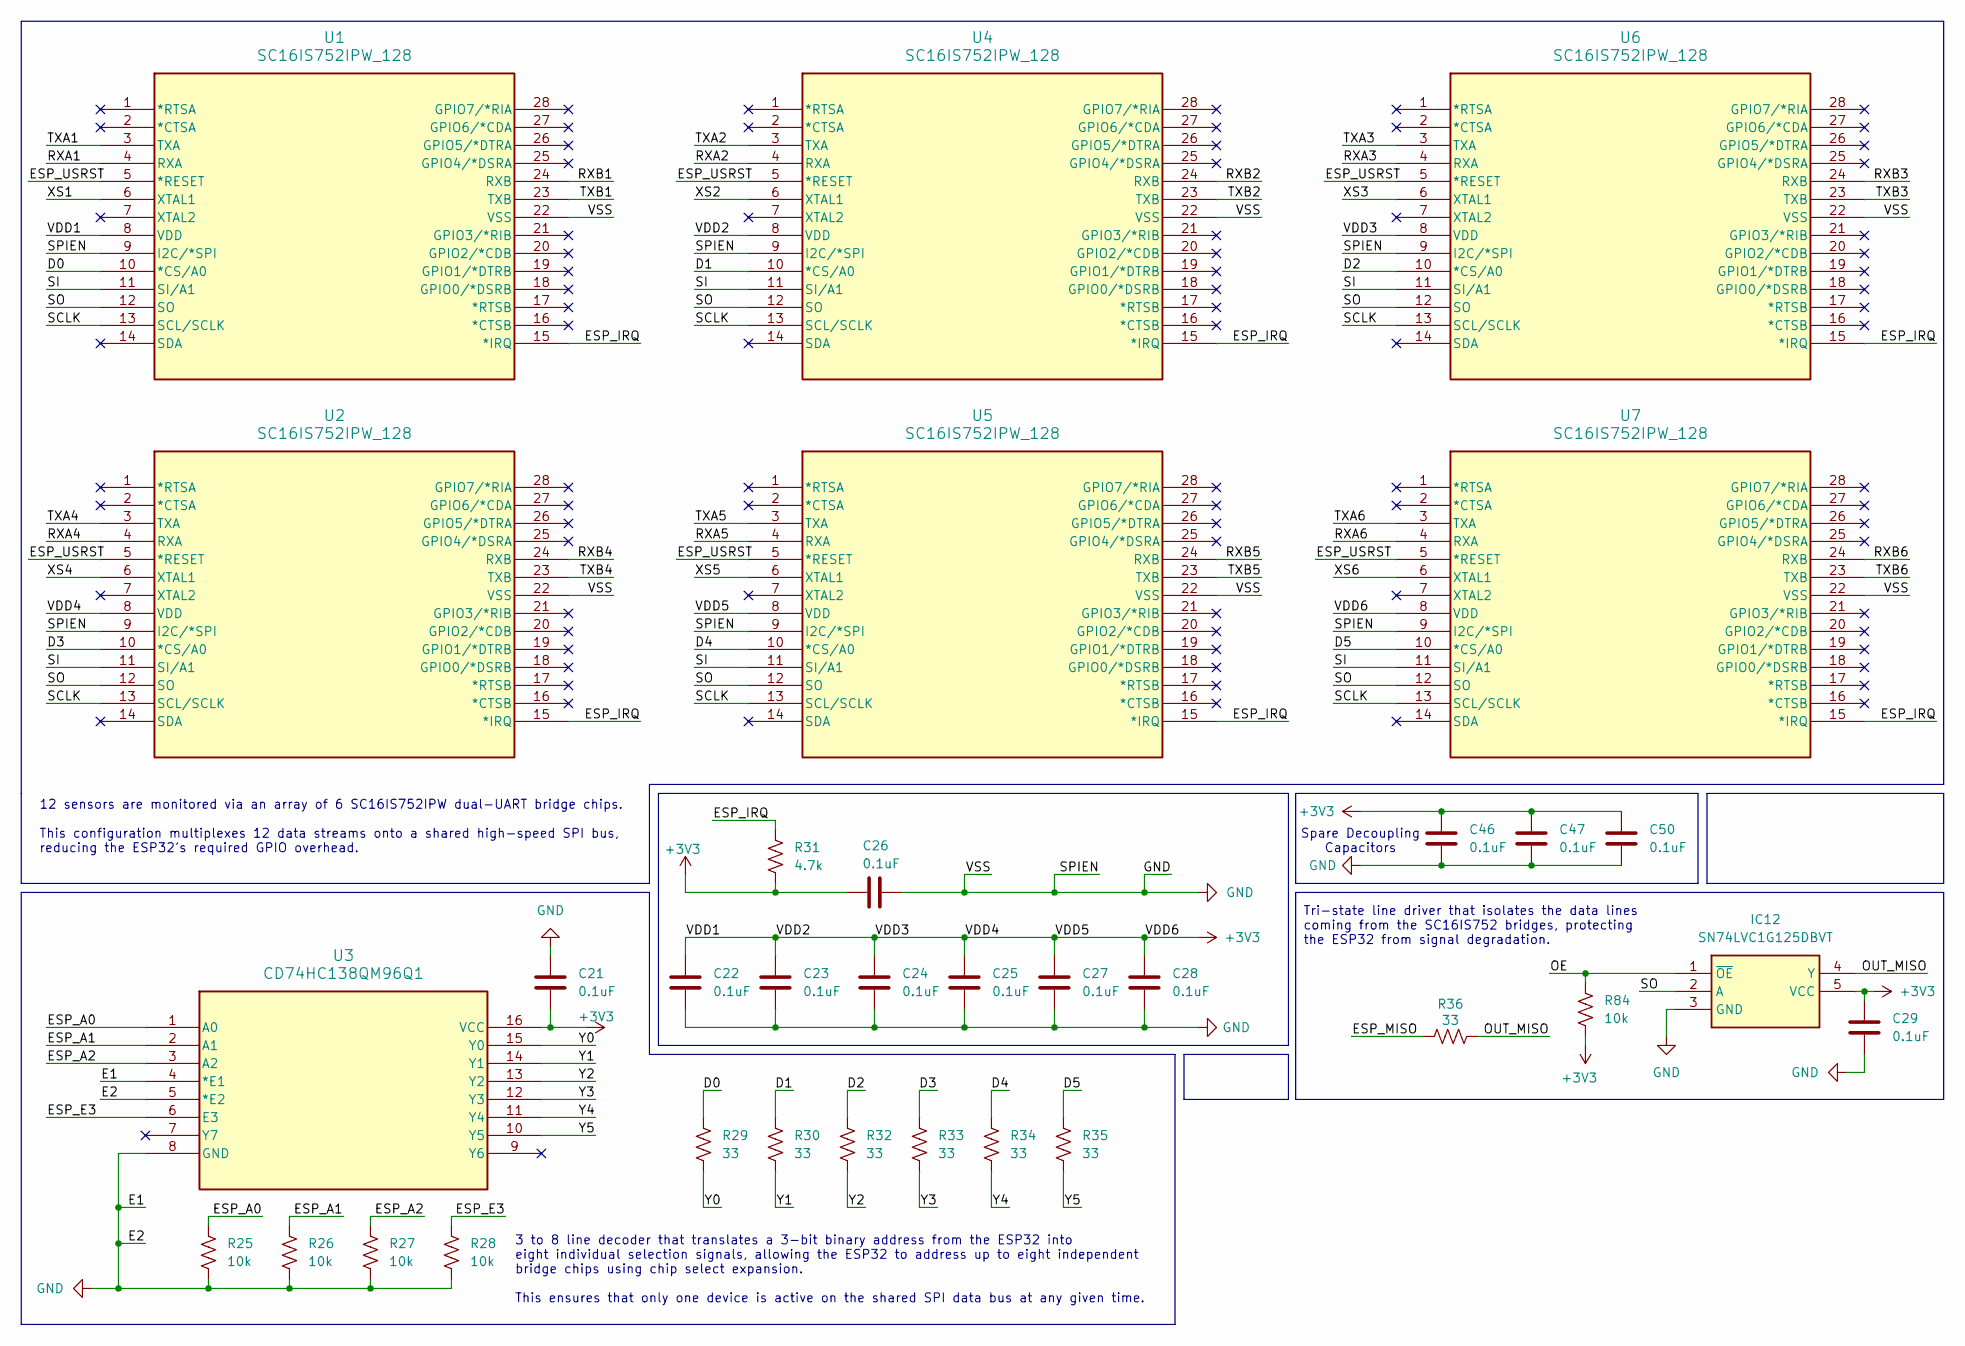
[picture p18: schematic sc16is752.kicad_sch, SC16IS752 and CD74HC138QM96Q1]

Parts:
C21, C22, C23, C24, C25, C26, C27, C28, C29, C46, C47, C50: 0.1uF; C_0805_2012Metric_Pad1.18x1.45mm_HandSolder; Manufacturer_Part_Number CL21B104KCC5PNC; Mouser Part Number 187-CL21B104KCC5PNC
IC12: SN74LVC1G125DBVT; SOT95P280X145-5N; Mouser Part Number 595-SN74LVC1G125DBVR
R25, R26, R27, R28, R84: 10k; R_0805_2012Metric_Pad1.20x1.40mm_HandSolder; Manufacturer_Part_Number ERA-6AEB103V; Mouser Part Number 667-ERA-6AEB103V
R29, R30, R32, R33, R34, R35, R36: 33; R_0805_2012Metric_Pad1.20x1.40mm_HandSolder; Manufacturer_Part_Number ERA-6AHD330V; Mouser Part Number 667-ERA-6AHD330V
R31: 4.7k; R_0805_2012Metric_Pad1.20x1.40mm_HandSolder; Manufacturer_Part_Number ERJ-UP6D4701V; Mouser Part Number 667-ERJ-UP6D4701V
U1, U2, U4, U5, U6, U7: SC16IS752IPW_128; TSSOP28_SOT361-1_NXP; Manufacturer_Part_Number SC16IS752IPW,128; Mouser Part Number 771-SC16IS752IPW128
U3: CD74HC138QM96Q1; D16; Manufacturer_Part_Number CD74HC138QM96Q1; Mouser Part Number 595-CD74HC138QM96Q1

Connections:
/D0: R29.1, U1.10 (*CS/A0)
/D1: R30.1, U4.10 (*CS/A0)
/D2: R32.1, U6.10 (*CS/A0)
/D3: R33.1, U2.10 (*CS/A0)
/D4: R34.1, U5.10 (*CS/A0)
/D5: R35.1, U7.10 (*CS/A0)
/ESP_A0: R25.1, U3.1 (A0); also elsewhere on the board
/ESP_A1: R26.1, U3.2 (A1); also elsewhere on the board
/ESP_A2: R27.1, U3.3 (A2); also elsewhere on the board
/ESP_E3: R28.2, U3.6 (E3); also elsewhere on the board
/ESP_IRQ: R31.2, U1.15 (*IRQ), U2.15 (*IRQ), U4.15 (*IRQ), U5.15 (*IRQ), U6.15 (*IRQ), U7.15 (*IRQ); also elsewhere on the board
/ESP_MISO: R36.1; also elsewhere on the board
/ESP_USRST: U1.5 (*RESET), U2.5 (*RESET), U4.5 (*RESET), U5.5 (*RESET), U6.5 (*RESET), U7.5 (*RESET); also elsewhere on the board
/OE: IC12.1 (~OE), R84.1; also elsewhere on the board
/OUT_MISO: IC12.4 (Y), R36.2
/RXA1: U1.4 (RXA); also elsewhere on the board
/RXA2: U4.4 (RXA); also elsewhere on the board
/RXA3: U6.4 (RXA); also elsewhere on the board
/RXA4: U2.4 (RXA); also elsewhere on the board
/RXA5: U5.4 (RXA); also elsewhere on the board
/RXA6: U7.4 (RXA); also elsewhere on the board
/RXB1: U1.24 (RXB); also elsewhere on the board
/RXB2: U4.24 (RXB); also elsewhere on the board
/RXB3: U6.24 (RXB); also elsewhere on the board
/RXB4: U2.24 (RXB); also elsewhere on the board
/RXB5: U5.24 (RXB); also elsewhere on the board
/RXB6: U7.24 (RXB); also elsewhere on the board
/SCLK: U1.13 (SCL/SCLK), U2.13 (SCL/SCLK), U4.13 (SCL/SCLK), U5.13 (SCL/SCLK), U6.13 (SCL/SCLK), U7.13 (SCL/SCLK); also elsewhere on the board
/SI: U1.11 (SI/A1), U2.11 (SI/A1), U4.11 (SI/A1), U5.11 (SI/A1), U6.11 (SI/A1), U7.11 (SI/A1); also elsewhere on the board
/SO: IC12.2 (A), U1.12 (SO), U2.12 (SO), U4.12 (SO), U5.12 (SO), U6.12 (SO), U7.12 (SO); also elsewhere on the board
/TXA1: U1.3 (TXA); also elsewhere on the board
/TXA2: U4.3 (TXA); also elsewhere on the board
/TXA3: U6.3 (TXA); also elsewhere on the board
/TXA4: U2.3 (TXA); also elsewhere on the board
/TXA5: U5.3 (TXA); also elsewhere on the board
/TXA6: U7.3 (TXA); also elsewhere on the board
/TXB1: U1.23 (TXB); also elsewhere on the board
/TXB2: U4.23 (TXB); also elsewhere on the board
/TXB3: U6.23 (TXB); also elsewhere on the board
/TXB4: U2.23 (TXB); also elsewhere on the board
/TXB5: U5.23 (TXB); also elsewhere on the board
/TXB6: U7.23 (TXB); also elsewhere on the board
/XS1: U1.6 (XTAL1); also elsewhere on the board
/XS2: U4.6 (XTAL1); also elsewhere on the board
/XS3: U6.6 (XTAL1); also elsewhere on the board
/XS4: U2.6 (XTAL1); also elsewhere on the board
/XS5: U5.6 (XTAL1); also elsewhere on the board
/XS6: U7.6 (XTAL1); also elsewhere on the board
/Y0: R29.2, U3.15 (Y0)
/Y1: R30.2, U3.14 (Y1)
/Y2: R32.2, U3.13 (Y2)
/Y3: R33.2, U3.12 (Y3)
/Y4: R34.2, U3.11 (Y4)
/Y5: R35.2, U3.10 (Y5)

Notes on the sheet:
3 to 8 line decoder that translates a 3-bit binary address from the ESP32 into eight individual selection signals, allowing the ESP32 to address up to eight independent bridge chips using chip select expansion. This ensures that only one device is active on the shared SPI data bus at any given time.
Tri-state line driver that isolates the data lines coming from the SC16IS752 bridges, protecting the ESP32 from signal degradation.
Spare Decoupling Capacitors
12 sensors are monitored via an array of 6 SC16IS752IPW dual-UART bridge chips. This configuration multiplexes 12 data streams onto a shared high-speed SPI bus, reducing the ESP32's required GPIO overhead.

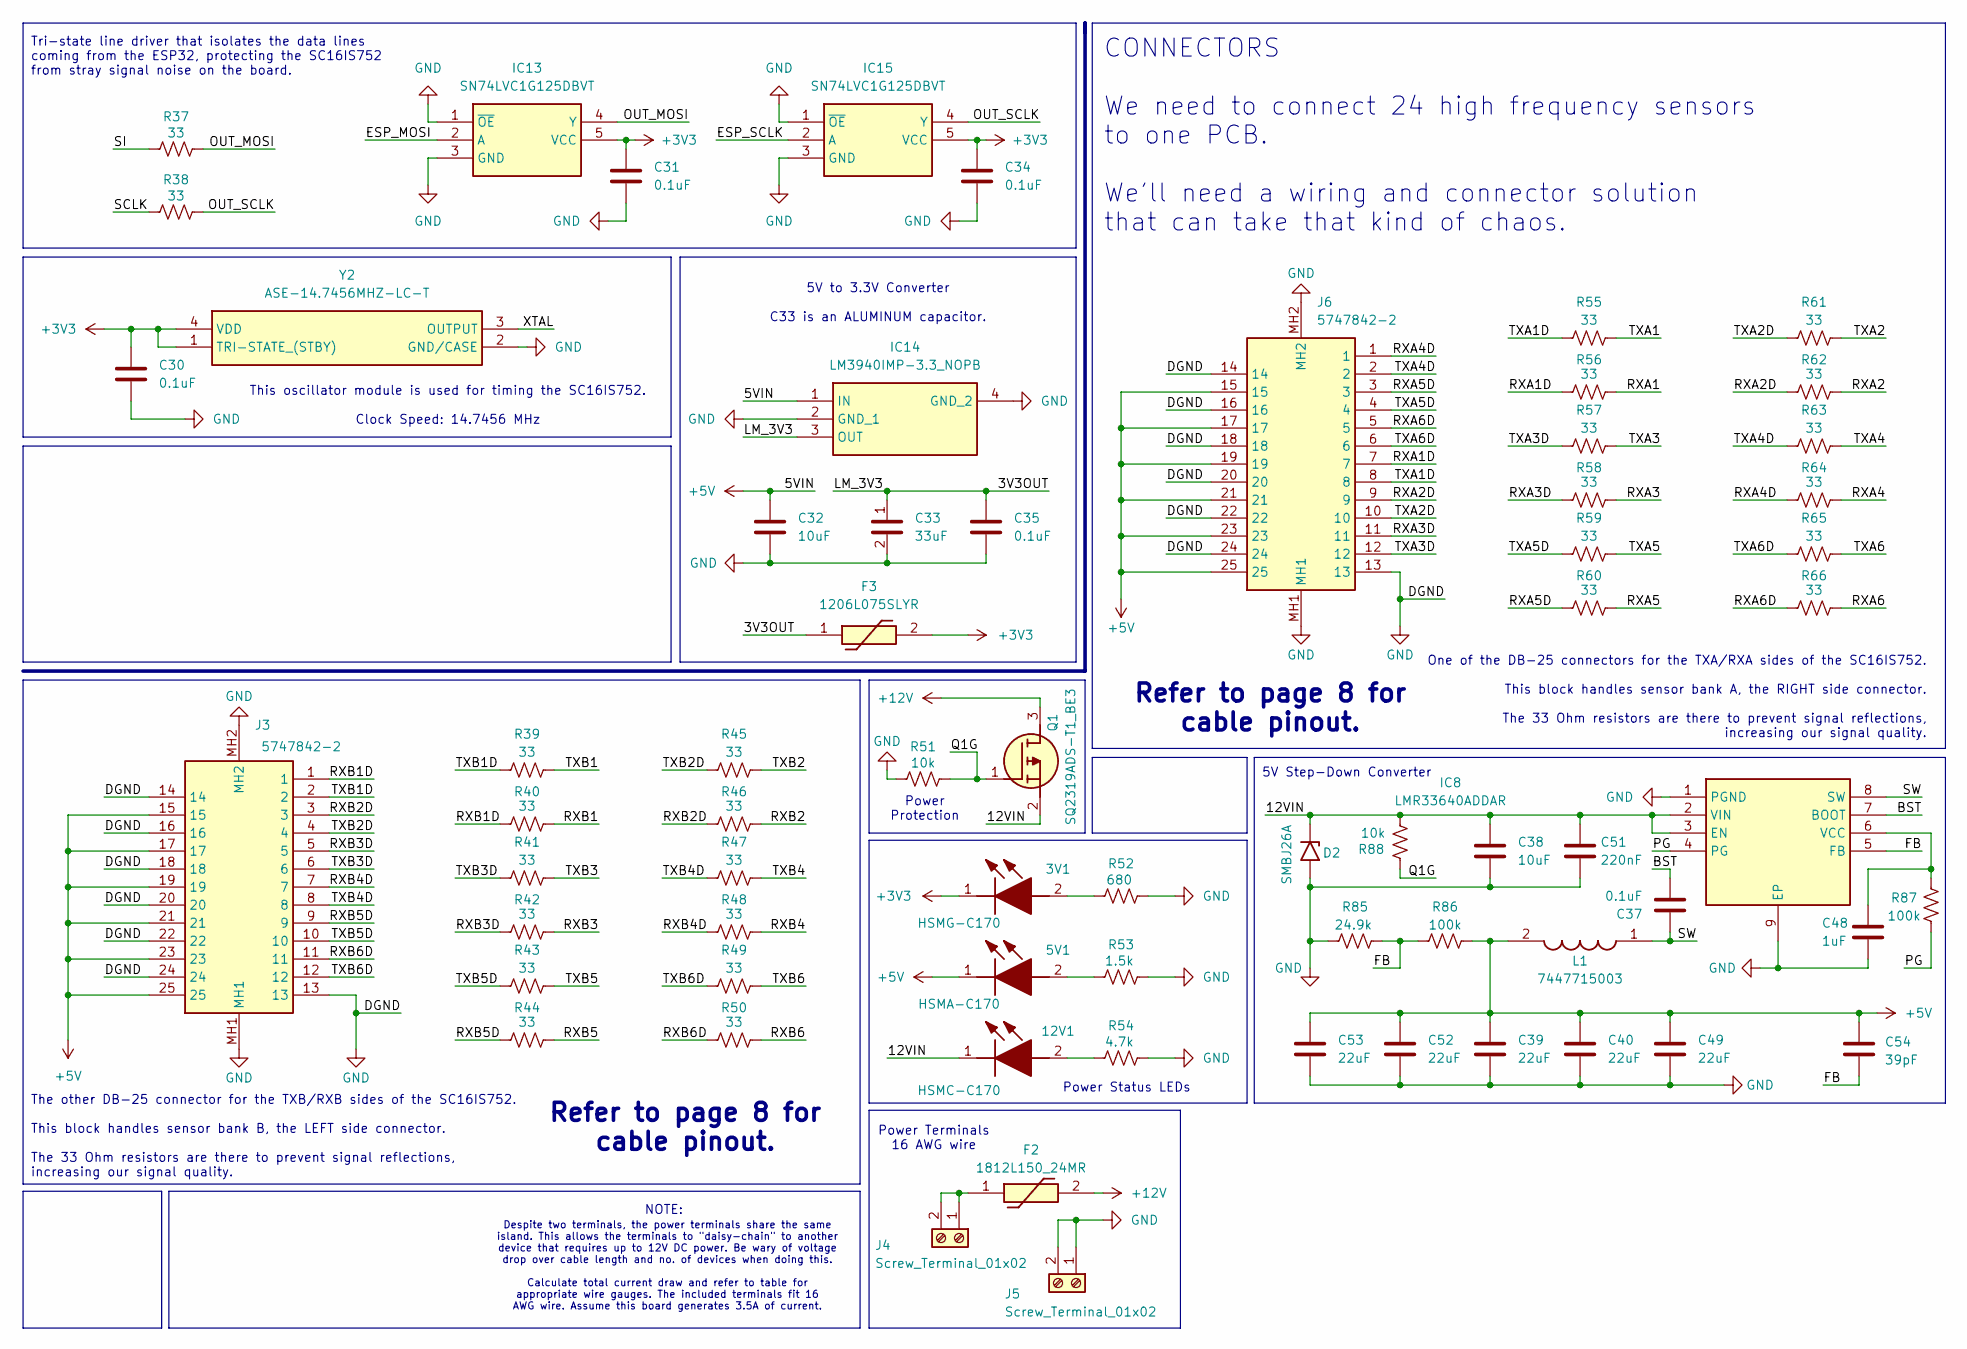
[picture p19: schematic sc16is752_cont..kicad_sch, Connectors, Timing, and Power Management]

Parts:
3V1: HSMG-C170; LEDC2012X80N; Mouser Part Number 630-HSMG-C170
5V1: HSMA-C170; LEDC2012X90N; Mouser Part Number 630-HSMA-C170
12V1: HSMC-C170; LEDC2012X90N; Mouser Part Number 630-HSMC-C170
C30, C31, C34, C35, C37: 0.1uF; C_0805_2012Metric_Pad1.18x1.45mm_HandSolder; Manufacturer_Part_Number CL21B104KCC5PNC; Mouser Part Number 187-CL21B104KCC5PNC
C32, C38: 10uF; C_0805_2012Metric_Pad1.18x1.45mm_HandSolder; Manufacturer_Part_Number CL21A106KBYQNNE; Mouser Part Number 187-CL21A106KBYQNNE
C33: 33uF; C_Elec_10x10.2; Manufacturer_Part_Number EEH-ZA1K330P; Mouser Part Number 667-EEH-ZA1K330P
C39, C40, C49, C52, C53: 22uF; C_0805_2012Metric_Pad1.18x1.45mm_HandSolder; Manufacturer_Part_Number CL21X226MQQNNNG; Mouser Part Number 187-CL21X226MQQNNNG
C48: 1uF; C_0805_2012Metric_Pad1.18x1.45mm_HandSolder; Manufacturer_Part_Number CL21B105KOFNNWE; Mouser Part Number 187-CL21B105KOFNNWE
C51: 220nF; C_0805_2012Metric_Pad1.18x1.45mm_HandSolder; Manufacturer_Part_Number CL21B224KBFNFNE; Mouser Part Number 187-CL21B224KBFNFNE
C54: 39pF; C_0805_2012Metric_Pad1.18x1.45mm_HandSolder; Manufacturer_Part_Number CL21C390JBANNNC; Mouser Part Number 187-CL21C390JBANNNC
D2: SMBJ26A; D_SMA; Manufacturer_Part_Number SMBJ26A; Mouser Part Number 576-SMBJ26A
F2: 1812L150_24MR; 1812L010DR; Mouser Part Number 576-1812L150/24MR
F3: 1206L075SLYR; Fuse_1206_3216Metric; Mouser Part Number 576-1206L075SLYR
IC8: LMR33640ADDAR; SOIC127P600X170-9N; Mouser Part Number 595-LMR33640ADDAR
IC13, IC15: SN74LVC1G125DBVT; SOT95P280X145-5N; Mouser Part Number 595-SN74LVC1G125DBVR
IC14: LM3940IMP-3.3_NOPB; SOT230P700X180-4N; Mouser Part Number 926-LM3940IMP3.3NOPB
J3, J6: 5747842-2; 57478422; Mouser Part Number 737-DB25-SA-M2
J4, J5: Screw_Terminal_01x02; TerminalBlock_Ningbo-Kagnex_HB9500M_1x02_P9.5mm; Manufacturer_Part_Number YK6010223000G; Mouser Part Number 649-YK6010223000G
L1: 7447715003; L_12x12mm_H4.5mm; Mouser Part Number 710-7447715003
Q1: SQ2319ADS-T1_BE3; SOT95P237X112-3N; Mouser Part Number 78-SQ2319ADS-T1_BE3
R37, R38, R39, R40, R41, R42, R43, R44, R45, R46, R47, R48, R49, R50, R55, R56, R57, R58, R59, R60, R61, R62, R63, R64, R65, R66: 33; R_0805_2012Metric_Pad1.20x1.40mm_HandSolder; Manufacturer_Part_Number ERA-6AHD330V; Mouser Part Number 667-ERA-6AHD330V
R51, R88: 10k; R_0805_2012Metric_Pad1.20x1.40mm_HandSolder; Manufacturer_Part_Number ERA-6AEB103V; Mouser Part Number 667-ERA-6AEB103V
R52: 680; R_0805_2012Metric_Pad1.20x1.40mm_HandSolder; Manufacturer_Part_Number ERJ-S06J681V; Mouser Part Number 667-ERJ-S06J681V
R53: 1.5k; R_0805_2012Metric_Pad1.20x1.40mm_HandSolder; Manufacturer_Part_Number ERA-6AEB152V; Mouser Part Number 667-ERA-6AEB152V
R54: 4.7k; R_0805_2012Metric_Pad1.20x1.40mm_HandSolder; Manufacturer_Part_Number ERJ-UP6D4701V; Mouser Part Number 667-ERJ-UP6D4701V
R85: 24.9k; R_0805_2012Metric_Pad1.20x1.40mm_HandSolder; Manufacturer_Part_Number ERJ-PB6B2492V; Mouser Part Number 667-ERJ-PB6B2492V
R86, R87: 100k; R_0805_2012Metric_Pad1.20x1.40mm_HandSolder; Manufacturer_Part_Number ERA-6AEB104V; Mouser Part Number 667-ERA-6AEB104V
Y2: ASE-14.7456MHZ-LC-T; ASE24576MHZLCT; Mouser Part Number 815-ASE14.7456MHZLCT

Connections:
+5V: 5V1.1 (K), C32.2, C39.2, C40.2, C49.2, C52.2, C53.2, C54.1, IC14.1 (IN), J3.15, J3.17, J3.19, J3.21, J3.23, J3.25, J6.15, J6.17, J6.19, J6.21, J6.23, J6.25, L1.2, R86.2; also elsewhere on the board
+12V: F2.2, Q1.3 (D)
/3V3OUT: C33.1, C35.2, F3.1, IC14.3 (OUT)
/12VIN: 12V1.1 (K), C38.2, C51.2, D2.1 (A1), IC8.2 (VIN), IC8.3 (EN), Q1.2 (S), R88.1; also elsewhere on the board
/BST: C37.1, IC8.7 (BOOT)
/ESP_MOSI: IC13.2 (A); also elsewhere on the board
/ESP_SCLK: IC15.2 (A); also elsewhere on the board
/FB: C54.2, IC8.5 (FB), R85.2, R86.1
/OUT_MOSI: IC13.4 (Y), R37.2
/OUT_SCLK: IC15.4 (Y), R38.2
/PG: IC8.4 (PG), R87.2
/Q1G: Q1.1 (G), R51.2, R88.2
/RXA1: R56.2; also elsewhere on the board
/RXA1D: J6.7, R56.1
/RXA2: R62.2; also elsewhere on the board
/RXA2D: J6.9, R62.1
/RXA3: R58.2; also elsewhere on the board
/RXA3D: J6.11, R58.1
/RXA4: R64.2; also elsewhere on the board
/RXA4D: J6.1, R64.1
/RXA5: R60.2; also elsewhere on the board
/RXA5D: J6.3, R60.1
/RXA6: R66.2; also elsewhere on the board
/RXA6D: J6.5, R66.1
/RXB1: R40.2; also elsewhere on the board
/RXB1D: J3.1, R40.1
/RXB2: R46.2; also elsewhere on the board
/RXB2D: J3.3, R46.1
/RXB3: R42.2; also elsewhere on the board
/RXB3D: J3.5, R42.1
/RXB4: R48.2; also elsewhere on the board
/RXB4D: J3.7, R48.1
/RXB5: R44.2; also elsewhere on the board
/RXB5D: J3.9, R44.1
/RXB6: R50.2; also elsewhere on the board
/RXB6D: J3.11, R50.1
/SCLK: R38.1; also elsewhere on the board
/SI: R37.1; also elsewhere on the board
/SW: C37.2, IC8.8 (SW), L1.1
/TXA1: R55.2; also elsewhere on the board
/TXA1D: J6.8, R55.1
/TXA2: R61.2; also elsewhere on the board
/TXA2D: J6.10, R61.1
/TXA3: R57.2; also elsewhere on the board
/TXA3D: J6.12, R57.1
/TXA4: R63.2; also elsewhere on the board
/TXA4D: J6.2, R63.1
/TXA5: R59.2; also elsewhere on the board
/TXA5D: J6.4, R59.1
/TXA6: R65.2; also elsewhere on the board
/TXA6D: J6.6, R65.1
/TXB1: R39.2; also elsewhere on the board
/TXB1D: J3.2, R39.1
/TXB2: R45.2; also elsewhere on the board
/TXB2D: J3.4, R45.1
/TXB3: R41.2; also elsewhere on the board
/TXB3D: J3.6, R41.1
/TXB4: R47.2; also elsewhere on the board
/TXB4D: J3.8, R47.1
/TXB5: R43.2; also elsewhere on the board
/TXB5D: J3.10, R43.1
/TXB6: R49.2; also elsewhere on the board
/TXB6D: J3.12, R49.1
unnamed: 3V1.2 (A), R52.1
unnamed: 5V1.2 (A), R53.1
unnamed: 12V1.2 (A), R54.1
unnamed: C48.2, IC8.6 (VCC), R87.1
unnamed: F2.1, J4.1, J4.2

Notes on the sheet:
Despite two terminals, the power terminals share the same island. This allows the terminals to "daisy-chain" to another device that requires up to 12V DC power. Be wary of voltage drop over cable length and no. of devices when doing this. Calculate total current draw and refer to table for appropri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
Refer to page 8 for cable pinout.
NOTE:
The other DB-25 connector for the TXB/RXB sides of the SC16IS752. This block handles sensor bank B, the LEFT side connector. The 33 Ohm resistors are there to prevent signal reflections, increasing our signal quality.
Power Terminals 16 AWG wire
5V to 3.3V Converter C33 is an ALUMINUM capacitor.
5V Step-Down Converter
Refer to page 8 for cable pinout.
CONNECTORS We need to connect 24 high frequency sensors to one PCB. We'll need a wiring and connector solution that can take that kind of chaos.
Tri-state line driver that isolates the data lines coming from the ESP32, protecting the SC16IS752 from stray signal noise on the board.
Power Protection
Power Status LEDs
One of the DB-25 connectors for the TXA/RXA sides of the SC16IS752. This block handles sensor bank A, the RIGHT side connector. The 33 Ohm resistors are there to prevent signal reflections, increasing our signal quality.
This oscillator module is used for timing the SC16IS752. Clock Speed: 14.7456 MHz

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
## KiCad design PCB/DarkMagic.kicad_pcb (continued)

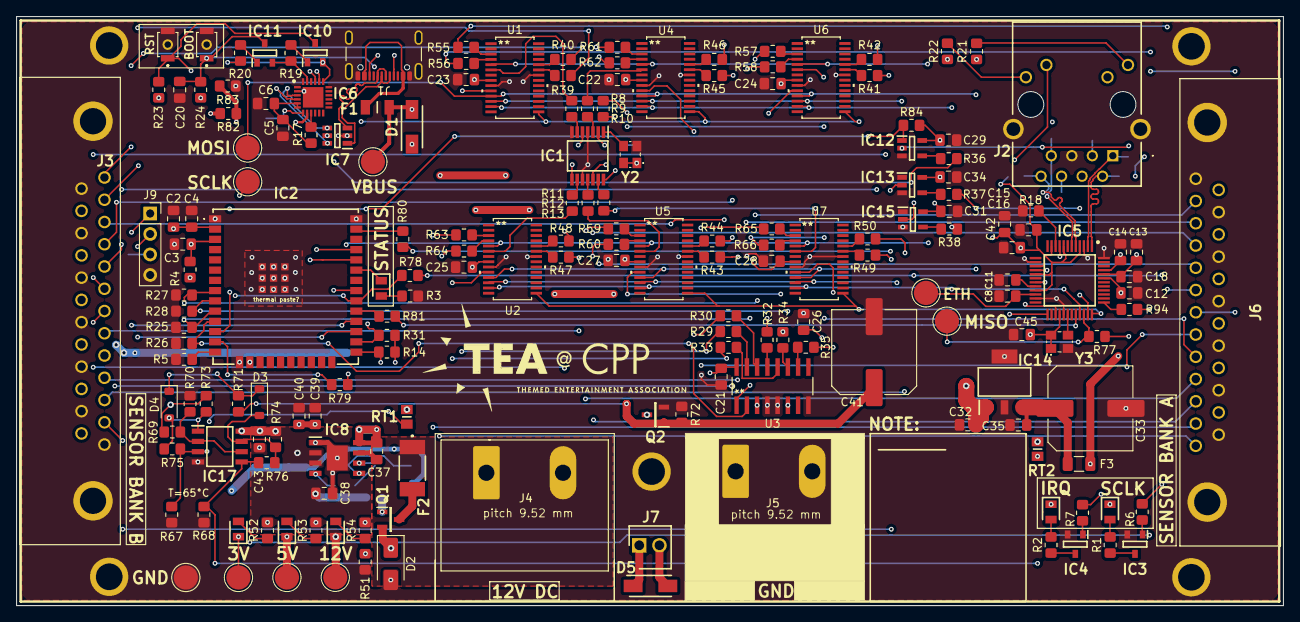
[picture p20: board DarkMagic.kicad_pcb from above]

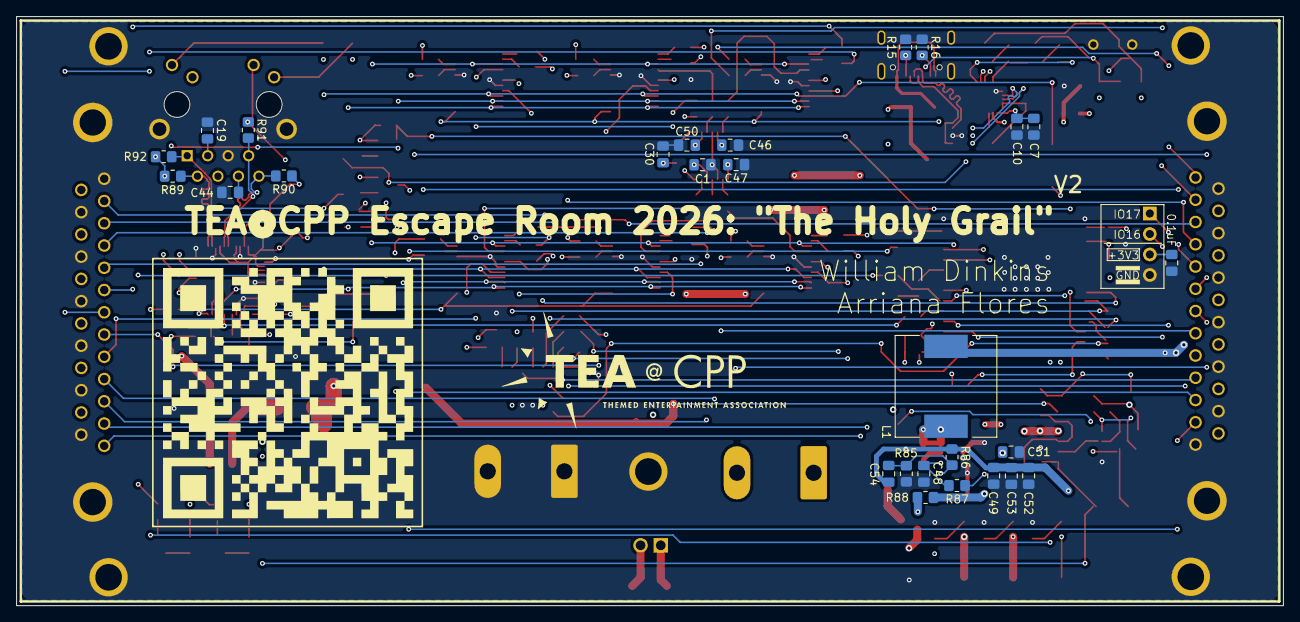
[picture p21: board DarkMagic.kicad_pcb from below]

Board: 6 copper layers, 157.0 x 73.0 mm, 212 parts (27 on the bottom side), 165 nets.

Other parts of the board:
C3, C4: 10uF; C_0805_2012Metric_Pad1.18x1.45mm_HandSolder
IC2: ESP32-WROOM-32UE-N16; ESP32WROOM32UEN16
IC3, IC4: MMBT3904-AQ; SOT95P240X120-3N
IRQ1: HSMN-C170; LEDC2012X90N
J9: Conn_01x04; PinSocket_1x04_P2.54mm_Vertical
R1, R2, R3: 330; R_0805_2012Metric_Pad1.20x1.40mm_HandSolder
R4, R5, R14: 10k; R_0805_2012Metric_Pad1.20x1.40mm_HandSolder
R6, R7: 4.7K; R_0805_2012Metric_Pad1.20x1.40mm_HandSolder
R8, R9, R10, R11, R12, R13: 33; R_0805_2012Metric_Pad1.20x1.40mm_HandSolder
SCLK1: HSMN-C170; LEDC2012X90N
STATUS1: HSMG-C170; LEDC2012X80N

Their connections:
/ESP_A0: IC2.10 (IO25); also elsewhere on the board
/ESP_A1: IC2.11 (IO26); also elsewhere on the board
/ESP_A2: IC2.8 (IO32); also elsewhere on the board
/ESP_E3: IC2.9 (IO33); also elsewhere on the board
/ESP_EN: C3.1, IC2.3 (EN), R4.1; also elsewhere on the board
/ESP_IO0: IC2.25 (IO0), R14.1; also elsewhere on the board
/ESP_IRQ: IC2.26 (IO4), R7.1; also elsewhere on the board
/ESP_MISO: IC2.31 (IO19); also elsewhere on the board
/ESP_MOSIT: IC2.37 (IO23); also elsewhere on the board
/ESP_RX0: IC2.34 (RXD0); also elsewhere on the board
/ESP_SCLK: R6.1; also elsewhere on the board
/ESP_SCLKT: IC2.30 (IO18); also elsewhere on the board
/ESP_SCSNT: IC2.29 (IO5); also elsewhere on the board
/ESP_TX0: IC2.35 (TXD0); also elsewhere on the board
/ESP_USRSTT: IC2.13 (IO14); also elsewhere on the board
/IO12: IC2.14 (IO12), R5.2
/IO16: IC2.27 (IO16), J9.2
/IO17: IC2.28 (IO17), J9.1
/IO21: IC2.33 (IO21), STATUS1.1 (K)
/IRQ_STAT: IC4.3 (C), R2.1
/OE: IC2.12 (IO27); also elsewhere on the board
/SCLK_STAT: IC3.3 (C), R1.1
/W5500_RST: IC2.16 (IO13); also elsewhere on the board
/XS1: R8.2; also elsewhere on the board
/XS1T: R8.1; also elsewhere on the board
/XS2: R9.2; also elsewhere on the board
/XS3: R10.2; also elsewhere on the board
/XS3T: R10.1; also elsewhere on the board
/XS4: R11.2; also elsewhere on the board
/XS4T: R11.1; also elsewhere on the board
/XS5: R12.2; also elsewhere on the board
/XS5T: R12.1; also elsewhere on the board
/XS6: R13.2; also elsewhere on the board
/XS6T: R13.1; also elsewhere on the board
unnamed: IC3.1 (B), R6.2
unnamed: IC4.1 (B), R7.2
unnamed: IRQ1.2 (A), R2.2
unnamed: R1.2, SCLK1.2 (A)
unnamed: R3.1, STATUS1.2 (A)

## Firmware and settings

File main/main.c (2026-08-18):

/**
 * @file main.c
 * @brief Main entry point for the Holy Grail custom aggregator board.
 *
 * Aggregates presence and distance data from 12 HLK-LD2410C radar sensors
 * using SPI-multiplexed SC16IS752 bridges, and publishes telemetry over
 * Ethernet (W5500) to an MQTT broker in JSON format.
 */

#include "driver/rtc_io.h"
#include "esp_err.h"
#include "esp_log.h"
#include "ethernet.h"
#include "freertos/FreeRTOS.h" // IWYU pragma: keep
#include "freertos/semphr.h"
#include "freertos/task.h"
#include "ld2410c.h"
#include "mqtt.h"
#include "rom/ets_sys.h"
#include "sc16is752.h"
#include <stdio.h>
#include <string.h>

static const char *TAG = "HolyGrail_Main";

/* Set to 1 to bypass Ethernet and print radar sensor telemetry to serial
 * monitor for testing */
#define DISABLE_ETHERNET_FOR_TESTING 1

/* ESP32 Hardware Pin Assignments based on Schematics */
#define ESP_SPI_HOST SPI3_HOST /**< Standard VSPI/SPI3 on ESP32 */
#define PIN_SPI_SCLK 18        /**< Shared SPI Clock */
#define PIN_SPI_MISO 19        /**< Shared SPI MISO */
#define PIN_SPI_MOSI 23        /**< Shared SPI MOSI */

/* CD74HC138 Line Decoder Pins */
#define PIN_DECODER_A0 25
#define PIN_DECODER_A1 26
#define PIN_DECODER_A2 32
#define PIN_DECODER_E3 33 /**< Active-High Enable */

/* W5500 Ethernet Pins */
#define PIN_W5500_CS 5   /**< Active-Low Chip Select */
#define PIN_W5500_RST 17 /**< W5500 Hardware Reset (IO17) */

/* SC16IS752 UART Bridge Reset Pin */
#define PIN_SC16IS752_RST 2 /**< SC16IS752 Hardware Reset (IO2, Active-Low) */

/* Dynamic MISO Buffer Isolation Pin (Tied to IC12 OE) */
#define PIN_MISO_OE 27 /**< Active-Low OE control */

/* Temporary 3.3V power source pin for W5500 Reset jumper testing */
#define PIN_W5500_RST_TEMP_3V3 16

/* Status LED */
#define PIN_STATUS_LED 21

/* Sensor Target Baud Rate */
#define SENSOR_BAUDRATE 115200 /**< LD2410C factory default baud rate */

/* Global Mutex for thread-safe access to sensor state table */
static SemaphoreHandle_t s_sensor_table_mutex = NULL;

/* Aggregated sensor state array */
typedef struct {
  char name[32];
  ld2410c_target_state_t state;
  uint16_t moving_distance_cm;
  uint8_t moving_energy;
  uint16_t stationary_distance_cm;
  uint8_t stationary_energy;
  uint16_t detection_distance_cm;
  bool is_online;
  uint8_t buffer[512];  /**< Accumulation buffer for fragmented UART frames */
  size_t buffer_len;    /**< Current number of bytes in the buffer */
} aggregated_sensor_data_t;

static aggregated_sensor_data_t s_sensor_telemetry[12];

/* Physical layout logical mapping */
typedef struct {
  uint8_t chip_idx;            /**< CD74HC138 address output index (0..5) */
  sc16is752_channel_t channel; /**< SC16IS752 UART channel (A or B) */
  const char *name;            /**< User-facing label */
} sensor_map_t;

const sensor_map_t SENSOR_MAP[12] = {
    {0, SC16IS752_CHAN_A, "BankA_Sensor1"}, // U1 Chan A
    {2, SC16IS752_CHAN_A, "BankA_Sensor2"}, // U4 Chan A
    {4, SC16IS752_CHAN_A, "BankA_Sensor3"}, // U6 Chan A
    {1, SC16IS752_CHAN_A, "BankA_Sensor4"}, // U2 Chan A
    {3, SC16IS752_CHAN_A, "BankA_Sensor5"}, // U5 Chan A
    {5, SC16IS752_CHAN_A, "BankA_Sensor6"}, // U7 Chan A
    {0, SC16IS752_CHAN_B, "BankB_Sensor1"}, // U1 Chan B
    {2, SC16IS752_CHAN_B, "BankB_Sensor2"}, // U4 Chan B
    {4, SC16IS752_CHAN_B, "BankB_Sensor3"}, // U6 Chan B
    {1, SC16IS752_CHAN_B, "BankB_Sensor4"}, // U2 Chan B
    {3, SC16IS752_CHAN_B, "BankB_Sensor5"}, // U5 Chan B
    {5, SC16IS752_CHAN_B, "BankB_Sensor6"}  // U7 Chan B
};

/**
 * @brief Initialize all board hardware peripherals.
 */
static void init_board_hardware(void) {
  ESP_LOGI(TAG, "Initializing Holy Grail hardware interfaces...");

  // 1. Install GPIO ISR service to prevent warning/error
  gpio_install_isr_service(0);

#if !DISABLE_ETHERNET_FOR_TESTING
  // Configure the old W5500 reset pin (GPIO13) as high-impedance input to avoid conflict
  // with the new GPIO17 reset bodge (they are shorted together via the J9 jumper).
  gpio_reset_pin(13);
  gpio_config_t config_gpio13 = {
      .intr_type = GPIO_INTR_DISABLE,
      .mode = GPIO_MODE_INPUT,
      .pin_bit_mask = (1ULL << 13),
      .pull_down_en = GPIO_PULLDOWN_DISABLE,
      .pull_up_en = GPIO_PULLUP_DISABLE};
  gpio_config(&config_gpio13);

  // Configure GPIO16 as output and execute a proper hardware reset pulse (GPIO16 is jumped to W5500 Reset)
  gpio_reset_pin(PIN_W5500_RST_TEMP_3V3);
  gpio_set_direction(PIN_W5500_RST_TEMP_3V3, GPIO_MODE_OUTPUT);
  gpio_set_level(PIN_W5500_RST_TEMP_3V3, 0); // Active-Low reset pulse
  vTaskDelay(pdMS_TO_TICKS(50));
  gpio_set_level(PIN_W5500_RST_TEMP_3V3, 1); // Release from reset
  vTaskDelay(pdMS_TO_TICKS(150)); // Wait for W5500 PLL to lock
#endif

  // 2. Pre-configure CS, RST, and Decoder Enable pins as outputs and set to
  // inactive state. This prevents bus contention on the shared MISO line at
  // boot.
  gpio_config_t rst_cs_conf = {
      .intr_type = GPIO_INTR_DISABLE,
      .mode = GPIO_MODE_OUTPUT,
      .pin_bit_mask = ((1ULL << PIN_W5500_CS) | (1ULL << PIN_W5500_RST) |
                       (1ULL << PIN_SC16IS752_RST) | (1ULL << PIN_MISO_OE) |
                       (1ULL << PIN_DECODER_E3)),
      .pull_down_en = GPIO_PULLDOWN_DISABLE,
      .pull_up_en = GPIO_PULLUP_DISABLE};
  gpio_config(&rst_cs_conf);

  // Set initial safe states: CS high, W5500 Reset high (running), SC16IS752
  // Reset high (running), MISO OE low (enabled), Decoder E3 low (disabled)
  gpio_set_level(PIN_W5500_CS, 1);
  gpio_set_level(PIN_W5500_RST, 1);
  gpio_set_level(PIN_SC16IS752_RST, 1); // Active-Low reset: HIGH to let it run
  gpio_set_level(PIN_MISO_OE, 0);
  gpio_set_level(PIN_DECODER_E3, 0);

  // 3. Pulse the Hardware Reset lines to reset W5500 and all SC16IS752 chips
  ESP_LOGI(TAG, "Executing hardware reset for W5500 and SC16IS752 array...");
  gpio_set_level(PIN_W5500_RST, 0);     // Reset W5500 (Active-Low)
  gpio_set_level(PIN_SC16IS752_RST, 0); // Reset SC16IS752 array (Active-Low)
  vTaskDelay(pdMS_TO_TICKS(10));        // Pulse for 10ms
  gpio_set_level(PIN_W5500_RST, 1);     // Release W5500 from reset
  gpio_set_level(PIN_SC16IS752_RST, 1); // Release SC16IS752 array from reset
  vTaskDelay(pdMS_TO_TICKS(
      150)); // Wait 150ms for chip PLLs and internal registers to stabilize

  // 4. Initialize Status LED
  gpio_config_t led_conf = {.intr_type = GPIO_INTR_DISABLE,
                            .mode = GPIO_MODE_OUTPUT,
                            .pin_bit_mask = (1ULL << PIN_STATUS_LED),
                            .pull_down_en = GPIO_PULLDOWN_DISABLE,
                            .pull_up_en = GPIO_PULLUP_DISABLE};
  gpio_config(&led_conf);
  gpio_set_level(PIN_STATUS_LED, 1); // Turn ON status LED on boot

  // 5. Initialize Shared SPI Bus
  spi_bus_config_t buscfg = {.miso_io_num = PIN_SPI_MISO,
                             .mosi_io_num = PIN_SPI_MOSI,
                             .sclk_io_num = PIN_SPI_SCLK,
                             .quadwp_io_num = -1,
                             .quadhd_io_num = -1,
                             .max_transfer_sz = 4096};
  ESP_ERROR_CHECK(spi_bus_initialize(ESP_SPI_HOST, &buscfg, SPI_DMA_DISABLED));

  // 6. Initialize Multiplexed SC16IS752 Driver
  sc16is752_hw_config_t sc_hw_cfg = {
      .spi_host = ESP_SPI_HOST,
      .pin_a0 = PIN_DECODER_A0,
      .pin_a1 = PIN_DECODER_A1,
      .pin_a2 = PIN_DECODER_A2,
      .pin_e3 = PIN_DECODER_E3,
      .pin_miso_oe = PIN_MISO_OE,
      .pin_irq = -1 // Polling mode is used for high-speed sensor aggregation
  };
  ESP_ERROR_CHECK(sc16is752_init(&sc_hw_cfg));

  // Configure all 12 physical UART channels for standard 230400 bps baud rate
  for (int i = 0; i < 12; i++) {
    const sensor_map_t *sensor = &SENSOR_MAP[i];
    esp_err_t ret = sc16is752_configure_uart(sensor->chip_idx, sensor->channel,
                                             SENSOR_BAUDRATE);
    if (ret == ESP_OK) {
      s_sensor_telemetry[i].is_online = true;
      strcpy(s_sensor_telemetry[i].name, sensor->name);
      s_sensor_telemetry[i].buffer_len = 0;
      s_sensor_telemetry[i].state = LD2410C_TARGET_NONE;
      ESP_LOGI(TAG, "Port successfully initialized: %s (Chip: %d, Chan: %d)",
               sensor->name, sensor->chip_idx, sensor->channel);
    } else {
      s_sensor_telemetry[i].is_online = false;
      ESP_LOGE(TAG, "Failed to initialize port: %s (Chip: %d, Chan: %d)",
               sensor->name, sensor->chip_idx, sensor->channel);
    }
  }

  // 7. Initialize W5500 Ethernet Controller
#if !DISABLE_ETHERNET_FOR_TESTING
  ethernet_config_t eth_cfg = {.spi_host = ESP_SPI_HOST,
                               .pin_cs = PIN_W5500_CS,
                               .pin_rst = PIN_W5500_RST,
                               .pin_intr = -1};
  ESP_ERROR_CHECK(ethernet_init(&eth_cfg));
#else
  ESP_LOGW(TAG, "Ethernet initialization BYPASSED for testing.");
#endif

  // Create thread safety mutex
  s_sensor_table_mutex = xSemaphoreCreateMutex();
  if (s_sensor_table_mutex == NULL) {
    ESP_LOGE(TAG, "Failed to create telemetry table mutex!");
  }
}

/**
 * @brief High-speed radar sensor aggregation loop.
 */
static void radar_aggregator_task(void *pvParameters) {
  ESP_LOGI(TAG, "Radar Aggregator task started.");
  uint8_t rx_buffer[64];

  while (1) {
    // Sequentially poll all 12 physical radar channels
    for (int i = 0; i < 12; i++) {
      if (!s_sensor_telemetry[i].is_online)
        continue;

      const sensor_map_t *sensor = &SENSOR_MAP[i];

      // Read pending serial bytes from the UART bridge
      int rx_len = sc16is752_read_bytes(sensor->chip_idx, sensor->channel,
                                        rx_buffer, sizeof(rx_buffer));
            if (rx_len > 0) {
        TickType_t now = xTaskGetTickCount();

        // 1. DEBUG LOGGING (RESTORED)
        static TickType_t last_rx_log_ticks[12] = {0};
        if (now - last_rx_log_ticks[i] >= pdMS_TO_TICKS(3000)) {
          last_rx_log_ticks[i] = now;
          char hex_str[128] = {0};
          size_t hex_str_len = 0;
          for (int b = 0; b < (rx_len > 16 ? 16 : rx_len); b++) {
            hex_str_len += snprintf(hex_str + hex_str_len, sizeof(hex_str) - hex_str_len, "%02X ", rx_buffer[b]);
          }
          ESP_LOGI(TAG, "Raw RX from [%s]: %d bytes: %s%s",
                   sensor->name, rx_len, hex_str, rx_len > 16 ? "..." : "");
        }

        // 2. Append newly received bytes to the sensor's persistent buffer
        if (s_sensor_telemetry[i].buffer_len + rx_len < sizeof(s_sensor_telemetry[i].buffer)) {
          memcpy(&s_sensor_telemetry[i].buffer[s_sensor_telemetry[i].buffer_len],
                 rx_buffer, rx_len);
          s_sensor_telemetry[i].buffer_len += rx_len;
        }
          // If no tail is found, we do nothing. We keep the bytes in the
          // buffer and wait for the next rx_len to provide the missing tail.

        // 3. Try to parse the accumulated buffer
        ld2410c_target_data_t target;
        if (ld2410c_parse_target_data(s_sensor_telemetry[i].buffer,
                                      s_sensor_telemetry[i].buffer_len,
                                      &target) == ESP_OK) {

          xSemaphoreTake(s_sensor_table_mutex, portMAX_DELAY);
          s_sensor_telemetry[i].state = target.state;
          s_sensor_telemetry[i].moving_distance_cm = target.moving_distance_cm;
          s_sensor_telemetry[i].moving_energy = target.moving_energy;
          s_sensor_telemetry[i].stationary_distance_cm = target.stationary_distance_cm;
          s_sensor_telemetry[i].stationary_energy = target.stationary_energy;
          s_sensor_telemetry[i].detection_distance_cm = target.detection_distance_cm;
          xSemaphoreGive(s_sensor_table_mutex);

          // 4. Clean up the buffer: Find the end of the frame (tail: F8 F7 F6 F5)
          // and remove everything up to that point to prepare for the next frame.
          uint8_t *tail_ptr = NULL;
          if (s_sensor_telemetry[i].buffer_len >= 4) {
            for (size_t j = 0; j <= s_sensor_telemetry[i].buffer_len - 4; j++) {
              if (s_sensor_telemetry[i].buffer[j] == 0xF8 &&
                  s_sensor_telemetry[i].buffer[j+1] == 0xF7 &&
                  s_sensor_telemetry[i].buffer[j+2] == 0xF6 &&
                  s_sensor_telemetry[i].buffer[j+3] == 0xF5) {
                tail_ptr = &s_sensor_telemetry[i].buffer[j + 4];
                break;
                        } else {
            // SYNC LOGIC: The parser failed. Search the buffer for the next potential 0xF4 0xF3 0xF2 0xF1 header.
            // If found, discard everything before it to "re-sync" the stream.
            uint8_t *sync_ptr = NULL;
            if (s_sensor_telemetry[i].buffer_len >= 4) {
              for (size_t j = 0; j <= s_sensor_telemetry[i].buffer_len - 4; j++) {
                if (s_sensor_telemetry[i].buffer[j] == 0xF4 &&
                    s_sensor_telemetry[i].buffer[j+1] == 0xF3 &&
                    s_sensor_telemetry[i].buffer[j+2] == 0xF2 &&
                    s_sensor_telemetry[i].buffer[j+3] == 0xF1) {
                  sync_ptr = &s_sensor_telemetry[i].buffer[j];
                  break;
                }
              }
            }

            if (sync_ptr != NULL) {
              size_t bytes_to_discard = sync_ptr - s_sensor_telemetry[i].buffer;
              memmove(s_sensor_telemetry[i].buffer,
                       s_sensor_telemetry[i].buffer + bytes_to_discard,
                       s_sensor_telemetry[i].buffer_len - bytes_to_discard);
              s_sensor_telemetry[i].buffer_len -= bytes_to_discard;
            } else {
              // If no header is found in the current buffer, clear it to prevent
              // continuous accumulation of junk.
              s_sensor_telemetry[i].buffer_len = 0;
            }
          }
            }
          }

          if (tail_ptr != NULL) {
            size_t bytes_to_remove = tail_ptr - s_sensor_telemetry[i].buffer;
            memmove(s_sensor_telemetry[i].buffer,
                     s_sensor_telemetry[i].buffer + bytes_to_remove,
                     s_sensor_telemetry[i].buffer_len - bytes_to_remove);
            s_sensor_telemetry[i].buffer_len -= bytes_to_remove;
          } else {
            // If no tail found, we reset the buffer to prevent stale data corruption
            s_sensor_telemetry[i].buffer_len = 0;
          }

#if DISABLE_ETHERNET_FOR_TESTING
          static TickType_t last_print_ticks[12] = {0};
          if (now - last_print_ticks[i] >= pdMS_TO_TICKS(500)) {
            last_print_ticks[i] = now;
          }
#else
          ESP_LOGD(TAG, "[%s] State: %d, MovDist: %d cm, StatDist: %d cm",
                   sensor->name, target.state, target.moving_distance_cm,
                   target.stationary_distance_cm);
#endif
        }
      }
    }

    // yield CPU to prevent starving lower priority threads (10 ms resolution)
    vTaskDelay(pdMS_TO_TICKS(10));
  }
}

/**
 * @brief Periodic publisher task sending telemetry JSON payload over Ethernet.
 */
static void telemetry_publish_task(void *pvParameters) {
  ESP_LOGI(TAG, "Telemetry publisher task started.");
  //char json_payload[2048];
  //bool mqtt_ready = false;

  while (1) {
    // Toggle Status LED as heart-beat indicator
    static int led_state = 0;
    gpio_set_level(PIN_STATUS_LED, led_state);
    led_state = !led_state;

#if DISABLE_ETHERNET_FOR_TESTING
    // Print custom formatted sensor data every 100ms
    static uint32_t line_count = 1;
    uint32_t timestamp = xTaskGetTickCount() * portTICK_PERIOD_MS;
    
    uint16_t readings[12];
    xSemaphoreTake(s_sensor_table_mutex, portMAX_DELAY);
    for (int i = 0; i < 12; i++) {
        if (s_sensor_telemetry[i].is_online && s_sensor_telemetry[i].state != LD2410C_TARGET_NONE) {
            readings[i] = s_sensor_telemetry[i].detection_distance_cm;
        } else {
            readings[i] = 0;
        }
    }
    xSemaphoreGive(s_sensor_table_mutex);

    printf("[%lu] [%lu] %d, %d, %d, %d, %d, %d, %d, %d, %d, %d, %d, %d\n",
           (unsigned long)timestamp,
           (unsigned long)line_count++,
           readings[0], readings[1], readings[2], readings[3], readings[4], readings[5],
           readings[6], readings[7], readings[8], readings[9], readings[10], readings[11]);
#else
    // Try to establish MQTT connection once Ethernet Link gets IP
    if (!mqtt_ready && ethernet_is_connected()) {
      ESP_LOGI(TAG,
               "Ethernet connection verified. Initializing MQTT client...");
      if (mqtt_init() == ESP_OK) {
        mqtt_ready = true;
      }
    }

    // If MQTT broker is active, publish latest data in JSON format
    if (mqtt_ready && mqtt_is_connected()) {
      size_t offset = 0;
      offset += snprintf(json_payload + offset, sizeof(json_payload) - offset,
                         "{\n  \"sensors\": [\n");

      xSemaphoreTake(s_sensor_table_mutex, portMAX_DELAY);
      for (int i = 0; i < 12; i++) {
        offset += snprintf(
            json_payload + offset, sizeof(json_payload) - offset,
            "    {\n"
            "      \"name\": \"%s\",\n"
            "      \"state\": %d,\n"
            "      \"moving_distance_cm\": %d,\n"
            "      \"moving_energy\": %d,\n"
            "      \"stationary_distance_cm\": %d,\n"
            "      \"stationary_energy\": %d\n"
            "    }%s\n",
            s_sensor_telemetry[i].name, s_sensor_telemetry[i].state,
            s_sensor_telemetry[i].moving_distance_cm,
            s_sensor_telemetry[i].moving_energy,
            s_sensor_telemetry[i].stationary_distance_cm,
            s_sensor_telemetry[i].stationary_energy, (i == 11) ? "" : ",");
      }
      xSemaphoreGive(s_sensor_table_mutex);

      offset += snprintf(json_payload + offset, sizeof(json_payload) - offset,
                         "  ]\n}");

      // Publish message
      mqtt_publish_telemetry(json_payload);
    }
#endif

    // Delay for 100ms (10Hz reporting speed for high-performance escape room
    // triggers)
    vTaskDelay(pdMS_TO_TICKS(100));
  }
}


void app_main(void) {
  esp_log_level_set("esp_netif", ESP_LOG_DEBUG);
  esp_log_level_set("lwip", ESP_LOG_DEBUG);
  esp_log_level_set("dhcp", ESP_LOG_DEBUG);
  esp_log_level_set("HolyGrail_MQTT", ESP_LOG_DEBUG);

  ESP_LOGI(TAG, "================================================");
  ESP_LOGI(TAG, "TEA@CPP Escape Room 2026: The Holy Grail");
  ESP_LOGI(TAG, "Custom Aggregator Board Firmware Booting...");
  ESP_LOGI(TAG, "================================================");

  // 1. Initialize all custom PCB components for normal operation
  init_board_hardware();

  // 3. Spawn high-speed radar polling thread
  xTaskCreatePinnedToCore(radar_aggregator_task, "radar_aggregator", 4096, NULL,
                          5, NULL, 0);

  // 4. Spawn periodic network publisher thread
  xTaskCreatePinnedToCore(telemetry_publish_task, "telemetry_publish", 4096,
                          NULL, 4, NULL, 1);
}

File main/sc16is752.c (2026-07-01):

/**
 * @file sc16is752.c
 * @brief SPI driver implementation for the SC16IS752 Dual UART-to-SPI bridge
 * controller.
 */

#include "sc16is752.h"
#include "esp_log.h"
#include "freertos/FreeRTOS.h" // IWYU pragma: keep
#include "freertos/semphr.h"
#include "freertos/task.h"
#include <string.h>

static const char *TAG = "SC16IS752";

/* SPI device handle */
static spi_device_handle_t s_spi_handle = NULL;
static sc16is752_hw_config_t s_hw_config;
static SemaphoreHandle_t s_spi_mutex = NULL;
static bool s_initialized = false;

esp_err_t sc16is752_init(const sc16is752_hw_config_t *config) {
  if (s_initialized) {
    ESP_LOGW(TAG, "SC16IS752 driver already initialized.");
    return ESP_OK;
  }

  ESP_LOGI(TAG, "Initializing SC16IS752 driver array...");
  memcpy(&s_hw_config, config, sizeof(sc16is752_hw_config_t));

  // Create the mutex for thread-safe shared SPI bus access
  s_spi_mutex = xSemaphoreCreateMutex();
  if (s_spi_mutex == NULL) {
    ESP_LOGE(TAG, "Failed to create SPI mutex!");
    return ESP_ERR_NO_MEM;
  }

  // 1. Configure the GPIOs for CD74HC138 addressing and enables
  gpio_config_t io_conf = {
      .intr_type = GPIO_INTR_DISABLE,
      .mode = GPIO_MODE_OUTPUT,
      .pin_bit_mask =
          ((1ULL << s_hw_config.pin_a0) | (1ULL << s_hw_config.pin_a1) |
           (1ULL << s_hw_config.pin_a2) | (1ULL << s_hw_config.pin_miso_oe)),
      .pull_down_en = GPIO_PULLDOWN_DISABLE,
      .pull_up_en = GPIO_PULLUP_DISABLE};
  ESP_ERROR_CHECK(gpio_config(&io_conf));

  // Keep CD74HC138 disabled (E3 LOW) and MISO buffer enabled (OE LOW) by
  // default (allows W5500 MISO communication)
  // Note: pin_e3 (GPIO33) is managed automatically by the SPI master peripheral below.
  gpio_set_level(s_hw_config.pin_miso_oe, 0);
  gpio_set_level(s_hw_config.pin_a0, 0);
  gpio_set_level(s_hw_config.pin_a1, 0);
  gpio_set_level(s_hw_config.pin_a2, 0);

  // 2. Add the SPI device to the shared SPI bus (CS managed by hardware SPI)
  spi_device_interface_config_t devcfg = {
      .clock_speed_hz =
          1 * 1000 *
          1000,           // 1 MHz SPI clock for signal integrity margin
      .mode = 0,          // SPI Mode 0
      .spics_io_num = s_hw_config.pin_e3, // Hardware SPI master controls decoder enable E3!
      .queue_size = 1,
      .flags = SPI_DEVICE_POSITIVE_CS | SPI_DEVICE_NO_DUMMY // E3 is Active-High Enable
  };

  esp_err_t ret =
      spi_bus_add_device(s_hw_config.spi_host, &devcfg, &s_spi_handle);
  if (ret != ESP_OK) {
    ESP_LOGE(TAG, "Failed to add SC16IS752 to SPI bus: %s",
             esp_err_to_name(ret));
    vQueueDelete(s_spi_mutex);
    return ret;
  }

  s_initialized = true;
  ESP_LOGI(TAG, "SC16IS752 multiplexer network configured successfully.");
  return ESP_OK;
}

esp_err_t sc16is752_select_chip(uint8_t chip_idx) {
  if (chip_idx >= 6) {
    return ESP_ERR_INVALID_ARG;
  }

  // Set A0, A1, A2 address bits
  gpio_set_level(s_hw_config.pin_a0, (chip_idx >> 0) & 0x01);
  gpio_set_level(s_hw_config.pin_a1, (chip_idx >> 1) & 0x01);
  gpio_set_level(s_hw_config.pin_a2, (chip_idx >> 2) & 0x01);

  // Enable MISO buffer (OE LOW)
  gpio_set_level(s_hw_config.pin_miso_oe, 0);

  return ESP_OK;
}

esp_err_t sc16is752_deselect_all(void) {
  // Keep MISO buffer enabled (OE LOW) for W5500 compatibility
  gpio_set_level(s_hw_config.pin_miso_oe, 0);

  return ESP_OK;
}

esp_err_t sc16is752_read_reg(uint8_t chip_idx, sc16is752_channel_t channel,
                             uint8_t reg_offset, uint8_t *out_val) {
  if (!s_initialized || s_spi_handle == NULL) {
    return ESP_ERR_INVALID_STATE;
  }

  // SPI address byte construction
  // Read flag (bit 7) = 1, Register offset (bits 6..3), Channel offset
  // (bits 2..1)
  uint8_t cmd_byte =
      0x80 | ((reg_offset & 0x0F) << 3) | ((channel & 0x03) << 1);

  uint8_t tx_data[2] = {cmd_byte, 0x00};
  uint8_t rx_data[2] = {0x00, 0x00};

  spi_transaction_t t;
  memset(&t, 0, sizeof(t));
  t.length = 16; // 16 bits (2 bytes)
  t.tx_buffer = tx_data;
  t.rx_buffer = rx_data;

  // Mutex locking for shared bus safety
  xSemaphoreTake(s_spi_mutex, portMAX_DELAY);

  // Hardware selection & bus setup
  sc16is752_select_chip(chip_idx);

  esp_err_t ret = spi_device_polling_transmit(s_spi_handle, &t);

  // Hardware deselect & isolation
  sc16is752_deselect_all();

  xSemaphoreGive(s_spi_mutex);

  if (ret == ESP_OK) {
    *out_val =
        rx_data[1]; // The second byte shifted out contains the register data
  }
  return ret;
}

esp_err_t sc16is752_write_reg(uint8_t chip_idx, sc16is752_channel_t channel,
                              uint8_t reg_offset, uint8_t val) {
  if (!s_initialized || s_spi_handle == NULL) {
    return ESP_ERR_INVALID_STATE;
  }

  // Write flag (bit 7) = 0, Register offset (bits 6..3), Channel offset
  // (bits 2..1)
  uint8_t cmd_byte = ((reg_offset & 0x0F) << 3) | ((channel & 0x03) << 1);

  uint8_t tx_data[2] = {cmd_byte, val};

  spi_transaction_t t;
  memset(&t, 0, sizeof(t));
  t.length = 16; // 16 bits
  t.tx_buffer = tx_data;

  xSemaphoreTake(s_spi_mutex, portMAX_DELAY);

  sc16is752_select_chip(chip_idx);

  esp_err_t ret = spi_device_polling_transmit(s_spi_handle, &t);

  sc16is752_deselect_all();

  xSemaphoreGive(s_spi_mutex);

  return ret;
}
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

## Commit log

2026-05-25 Add ESP-IDF devcontainer and project scaffold
    Initial scaffold for an ESP-IDF project: adds a devcontainer (Dockerfile + devcontainer.json) using espressif/idf, installs udev, and sources the ESP-IDF environment. Includes VS Code configs (c_cpp_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
2026-05-25 feat: initialize LD2410C radar sensor integration and target tracking application
2026-05-25 docs: add project documentation and schematic reference for The Holy Grail PCB
2026-05-26 feat: implement W5500 Ethernet driver and MQTT client for HolyGrail radar data aggregation
2026-05-26 Update DarkMagic.pdf
    Updated schematic
2026-05-26 PCB Layout
    Uploaded the KiCad project here
    [DarkMagic-5_3V3_Cu.gbr, DarkMagic-B_Mask.gbr, DarkMagic-B_Silkscreen.gbr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]
2026-05-26 File organizing
    [DarkMagic.csv]
2026-05-26 Update README with image and PCB details
    Added an image and expanded the description of the Holy Grail PCB.
2026-05-26 Update DarkMagic PCB and add production files
    Clean up and adjust DarkMagic.kicad_pcb geometry (remove stray segments, tweak segment endpoints and UUIDs, and refine track/polyline coordinates). Add production outputs and artifacts for manufactur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
    [bom.csv, designators.csv, positions.csv]
2026-05-26 Capacitor placement
    Moved some decoupling caps from the top to the bottom. Also, file organization
    [esp32.kicad_sch, sc16is752.kicad_sch]
2026-05-26 Wiring
    Tweaked wiring
2026-05-26 Add footprints & datasheets; clean PCB file
    Add numerous component datasheets to PCB/Datasheets and introduce new footprints (DarkMagic:SRN2010BTA3R3M and DarkMagic:1812L010DR). Remove many redundant KiLib_Generator properties and perform footprint edits across the board including placement/rotation changes, pad orientation/net fixes, value and UUID updates, and silkscreen/fab text adjustments. Also add KiCad editor lock files (~DarkMagic.kicad_pcb.lck, ~DarkMagic.kicad_sch.lck).
    [sc16is752.kicad_sch, sc16is752_cont..kicad_sch]
2026-05-27 Revise PCB footprints, nets and metadata
    Refactor multiple footprints and metadata across the DarkMagic PCB files. Removed an obsolete SRN2010 inductor footprint and replaced a capacitor footprint with Inductor_SMD:L_12x12mm_H4.5mm (L1). Standardized net names (e.g. Net-(Q1-G) -> /Q1G), adjusted pad rotations/positions and many silkscreen/fab/crt geometry coordinates, and updated UUIDs and 3D model/part properties. Also updated component reference positions for a few ICs and capacitors and removed a stale KiCad schematic lock file. These edits clean up footprints, ensure consistent metadata and correct layout geometry for fabrication/assembly.
    [sc16is752_cont..kicad_sch, sensor_pinout.kicad_sch]
2026-05-27 Silkscreen to 12V and major PCB reroute
    Update silkscreen and documentation from 24V to 12V (text and warning box) and adjust a small graphic line position. Perform extensive PCB rework: replace and reassign many segments/vias, add new nets and route changes (examples: /IO12, /VBG, Net-(STATUS1-A), /TXB1D, /Q1G, /1IN+, /1IN-, /IO21, /ESP_USRST, /TXA5D), set trace widths/layers (mostly 0.2), and add vias for revised layer transitions. These changes reorganize signal routing and add gate/input nets (Q1G, 1IN+/1IN-) to match the updated board design. Also update PCB project file (.kicad_prl) alongside the .kicad_pcb modifications.
2026-05-27 Update BOM parts and adjust schematics text/layout
    Apply multiple BOM updates and schematic edits: replace/update capacitor, diode, TVS, fuse, regulator, transistor, connector and resistor part numbers and quantities in DarkMagic.csv; add new components (C48/C51/C54, R85-R87, etc.). Change board active layer in DarkMagic.kicad_prl (9 -> 0). Update manufacturer/mouser part numbers for decoupling caps in esp32.kicad_sch and sc16is752_cont..kicad_sch. Tweak sheet text positions/fonts and remove a sentence in sc16is752_cont..kicad_sch, and add a printable installer-sign text block to sensor_pinout.kicad_sch for cable verification. These edits reflect revised part selections and improve schematic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
    [DarkMagic.csv, esp32.kicad_sch, sc16is752_cont..kicad_sch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]
2026-05-27 Update PCB layout, BOM and production files
    Multiple PCB and production updates: adjust component reference positions/rotations and silkscreen stroke widths; clear zone_layer_connections entries; add/remove vias and modify several copper segme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
    [bom.csv, designators.csv, positions.csv]
2026-05-28 PCB Layout optimizations
    [esp32.kicad_sch]
2026-05-28 KiCad: adjust PCB coords, routing & schematic
    Minor PCB and schematic tweaks: update resistor and via Y coordinates in DarkMagic.kicad_pcb, adjust F.Cu routing segments (added one segment, changed segment endpoints and UUIDs) to clean up trace geometry, and change active_layer from 2 to 5 in DarkMagic.kicad_prl. Also correct schematic text in fan_controller.kicad_sch (LM3460 -> LMR33640) to fix part reference/notes.
    [fan_controller.kicad_sch]
2026-05-28 Add 1x04 pin socket and clean footprint attrs
    Inserted a new 1x04 vertical pin socket footprint (J9) for the ESP32 connector and added corresponding silk labels for IO pins. Removed stray "dnp" attributes from multiple footprint pad definitions 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
    [esp32.kicad_sch]
2026-05-29 Move R15/R16 to bottom side and clean generated files
    Replace front-side R15/R16 footprints with mirrored bottom-side footprints (moved from F.Cu to B.Cu), updating silk/fab text mirroring and pad layers. Remove duplicate front-side footprint entries. Delete generated fabrication outputs in PCB/PCB/ (Gerbers, drills, job, PDF) and update fabrication-toolkit-options.json and production assets (Holy_Grail.zip, designators.csv, netlist.ipc, positions.csv). Also applied a small silk/font tweak (removed italic) and adjusted board polygon coordinates.
    [DarkMagic-5_3V3_Cu.gbr, DarkMagic-B_Mask.gbr, DarkMagic-B_Silkscreen.gbr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]
2026-05-30 Add bottom hand-solder caps and update BOM
    Update PCB to add bottom-side hand-solder 0805 capacitor footprints and sync BOM. DarkMagic.csv: increment 0.1uF part count (34→35) and 4.7uF count (1→2) and update component lists. DarkMagic.kicad_p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
    [DarkMagic.csv, bom.csv, designators.csv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]
2026-05-31 Add four 49.9Ω resistors and update PCB
    Add R89–R92 as 49.9Ω SMD 0805 hand-solder footprints and corresponding BOM entries. Update PCB layout with new footprints, vias and copper segments to connect the parts into +3V3 and related signal n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
    [DarkMagic.csv, bom.csv, designators.csv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]
2026-05-31 Adjust PCB spline vertex coordinates
    Tweak several (xy ...) control points in PCB/DarkMagic.kicad_pcb to correct and smooth spline/outline geometry. The changes are minor coordinate adjustments to refine the board outline and rendering; the corresponding PCB project file (PCB/DarkMagic.kicad_prl) was updated alongside.
2026-06-01 PCB: change mask color, pad & routing fixes
    Update PCB and project files: DarkMagic.kicad_pcb had solder mask color changed from Black to Green, multiple pad definitions converted from np_thru_hole to thru_hole (add remove_unused_layers where needed) and a GND net applied to a pad. Adjusted component positions for several SMD capacitors, moved vias and re-routed/cleaned up multiple track segments (with associated UUID refreshes). Misc UUIDs refreshed across footprints and text items. Also updated related project files (DarkMagic.kicad_prl, DarkMagic.kicad_pro, sc16is752_cont..kicad_sch) and added PCB/sensor_pinout.pdf.
    [sc16is752_cont..kicad_sch]
2026-06-05 Connect GND zones to In2.Cu layer
    Add In2.Cu to multiple zone_layer_connections for GND zones in DarkMagic.kicad_pcb so ground pours can use the inner layer. Also update several F.Cu filled_polygon shapes (polygon geometry replaced/simplified) and remove the temporary schematic lock file (~DarkMagic.kicad_sch.lck). Project metadata (DarkMagic.kicad_prl) and generated BOM (ibom.html) were updated as part of these changes.
2026-06-21 PCB: Reroute nets and update component value
    Modify DarkMagic.kicad_pcb to correct power routing and update a component value. Changes include: changed a component Value from "CDCLVC1106PWR" to "5PB1106PGGI8", reassigned a pad/net from GND to +3V3, moved a via, removed and added several F.Cu segments (cleaned up GND segments and added +3V3 traces), and adjusted a board polygon/outline coordinate. These edits fix net connections and reflect the correct part designation in the PCB layout.
    [esp32.kicad_sch, ethernet_port.kicad_sch]
2026-06-22 Add 0805 handsolder footprint and reroute nets
    Add an 0805 hand-solder capacitor footprint (Pad1.18x1.45mm) on B.Cu (C50) and update existing 0805 footprint reference placement. Add copper segments and a via to connect +3V3 and GND between F.Cu and B.Cu (including new via at 148.675,37.84). Re-route several F.Cu traces (ESP_A1 and +3V3) and update segment coordinates/UUIDs. Adjust a copper zone (changed layer to F.Mask and lowered priority) and remove/replace some filled polygons. Update associated project/schematic metadata files and add schematic lock file.
    [esp32.kicad_sch, sc16is752.kicad_sch]
2026-06-27 V2 Polishing
    Minor layout optimizations, including removed vias and rerouted power rails
    [ethernet_port.kicad_sch]
2026-06-28 feat: initialize project with ESP32 schematic, ethernet port layout, and base firmware.
    [esp32.kicad_sch, ethernet_port.kicad_sch]
2026-07-01 Board Modifications and Initial Comms w/ Sensors
    Modified wiring to separate ethernet reset from SC16 reset, adjusted pinouts and power, worked on code to get board talking to sensors. Ethernet still needs a bodge wire at this point.
    [DarkMagic-B_Mask.gbs, DarkMagic-B_Paste.gbp, DarkMagic-B_Silkscreen.gbo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]
2026-07-03 Diagnosing Ethernet Controller
    The Ethernet chip is dead, we'll need a new one. Minor optimizations everywhere.
    [DarkMagic.kicad_pcb, esp32.kicad_sch, fan_controller.kicad_sch]
2026-07-03 Adjust PCB layout and update capacitor value
    Fix IC5 (W5500) reference rotation from 180° to 0°. Reposition C8 capacitor and reorganize W5500_RST routing traces. Update ethernet port capacitor value from 10nF to 4.7uF.
    [DarkMagic.kicad_pcb, ethernet_port.kicad_sch]
2026-07-04 The W5500 actually works, I just wired it wrong
    Pulled back some pins and it's working now! Fixed this error in schematic, code was updated to reflect this
    [DarkMagic.kicad_pcb, ethernet_port.kicad_sch]
2026-07-08 Updated PDF schematic, tweaked connections
    [DarkMagic.kicad_pcb, ethernet_port.kicad_sch, fan_controller.kicad_sch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]
2026-07-17 feat: initialize KiCad project and MQTT header with main application scaffold, removed diagnostic feats
2026-08-12 Touch-ups
    Various minor improvements
    [DarkMagic.kicad_pcb, ethernet_port.kicad_sch, sc16is752_cont..kicad_sch]
2026-08-18 Handle fragmented UART frames; set sensor baud to 115200
    Change sensor baud to LD2410C factory default (115200). Add a 512-byte accumulation buffer and buffer_len to aggregated_sensor_data_t and initialize it during board setup. In radar_aggregator_task, restore rate-limited raw RX debug logging, append incoming UART bytes into the per-sensor buffer, then parse accumulated data. On successful parse update telemetry and remove processed bytes using tail (F8 F7 F6 F5) detection; if parsing fails attempt resync by searching for the header (F4 F3 F2 F1), otherwise clear buffer to avoid junk accumulation. Also commented out unused json_payload/mqtt_ready variables.
    [main.c]
